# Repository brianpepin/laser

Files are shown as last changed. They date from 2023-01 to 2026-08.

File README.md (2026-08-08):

# The Laser Project
This repository contains a design for a diode pumped solid state laser that emits a green 532nm beam.  The unit is battery operated and rechargable with a runtime of approximately 30 minutes.

## Versions
Version 2.1 of the hardware and software is now live. Here is a summary of the changes:
1. The control board now uses a more modern MCU. Display refreshes are 8x faster and I was able to remove a number of components from the board due to the enhanced peripheral support on the new MCU.
2. Encoders are now velocity sensitive.
3. Calibration for the output power monitor now can be done through the UI.
4. The laser design has changed and the maximum output power is now 3x what it was in version 1.

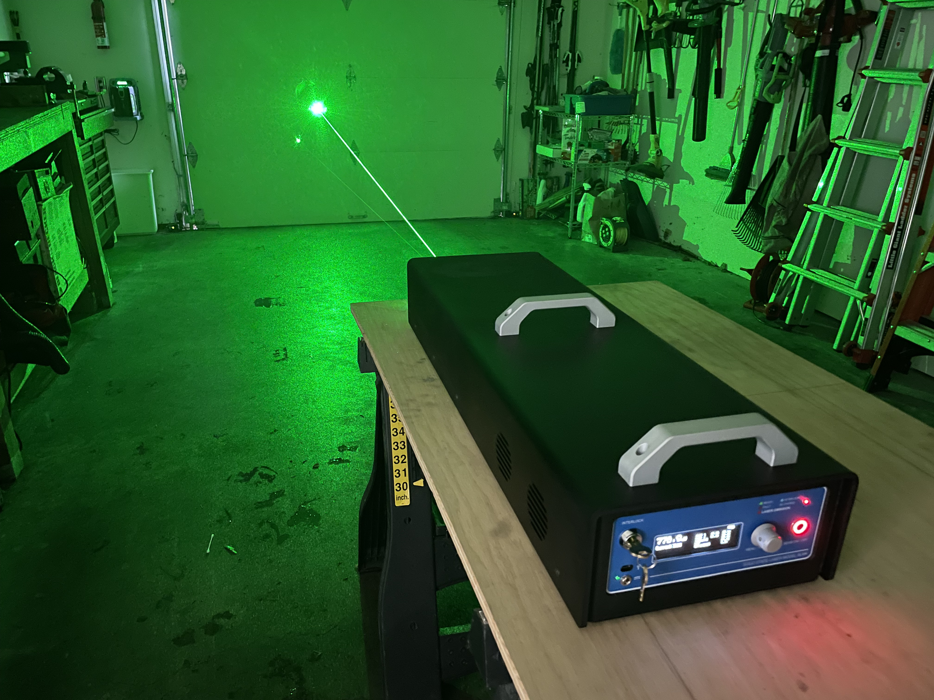
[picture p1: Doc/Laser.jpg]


## Repository Organization

The repository contains the following directories.

### Hardware
The Hardware directory contains KiCad files for schematics and board designs for the electronics.  There are three boards in total:

1. The **Power** board is the main power supply. It contains a battery charger, power control, power monitoring, fan controller, and two 50A constant current power supplies.
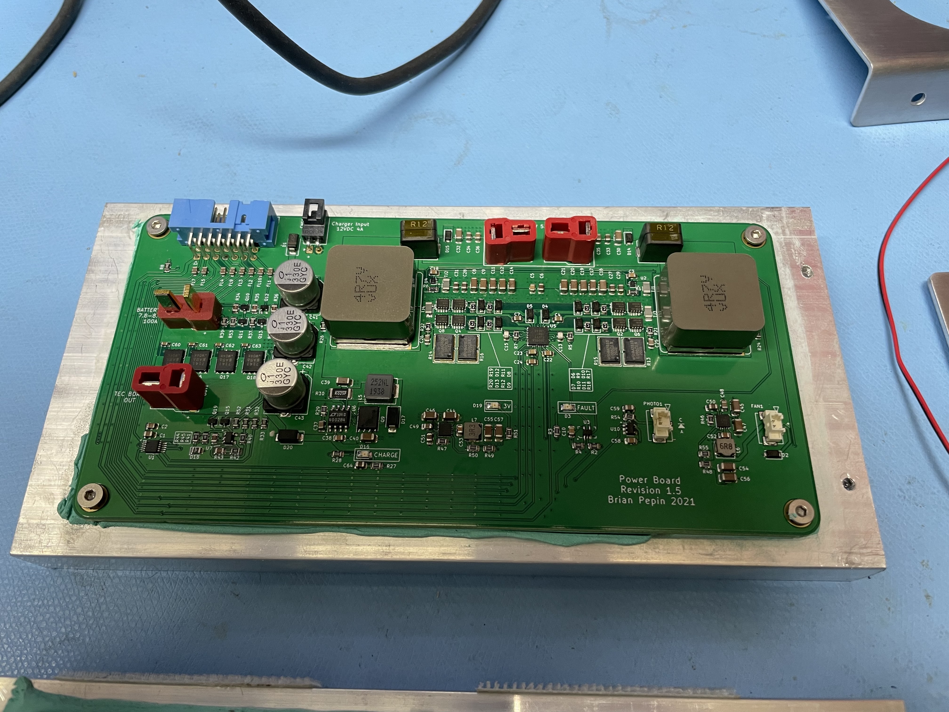
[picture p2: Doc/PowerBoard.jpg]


2. The **TEC** board contains four independent channels for controlling thermo-electric coolers. Each channel can control up to 20A of cooling using direct battery voltage.
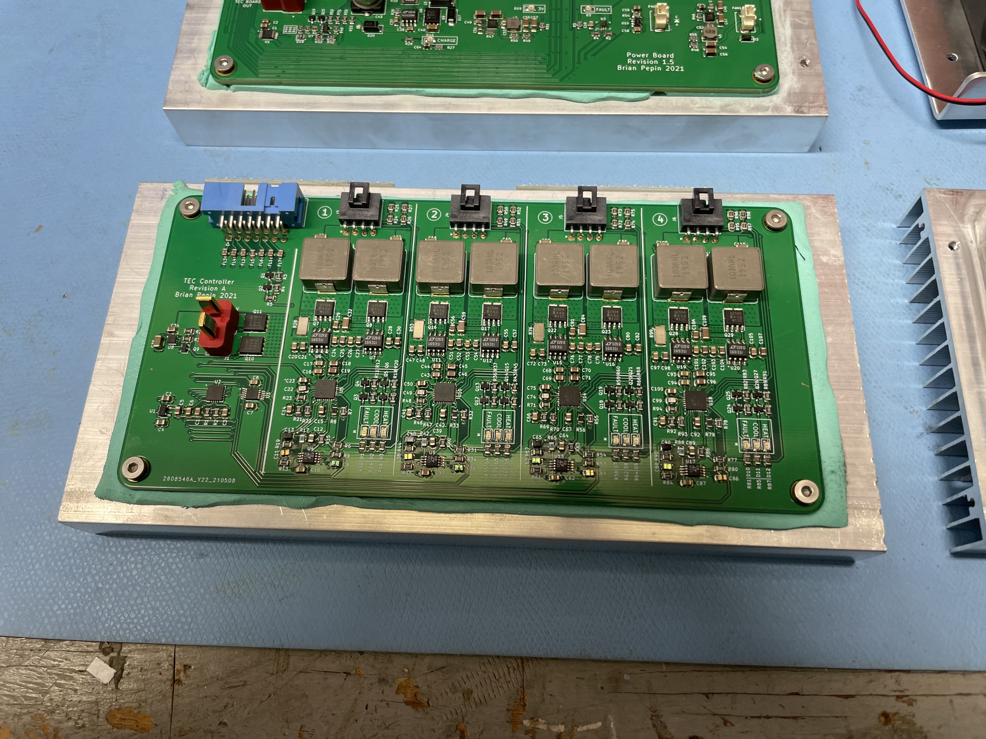
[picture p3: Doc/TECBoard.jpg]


3. The **Control** board is a small MCU and display for running the laser.  The board is based on the aging ATMEGA328p....but it would be easy to swap this to a newer MCU.

**Update:** Version 2.1 of the hardware now uses AVR128DB64 as it's MCU. This MCU has a lot more memory, a much faster speed, and perhipherial updates (like controllable schmitt triggers on inputs) that greatly simplified the rest of the board.

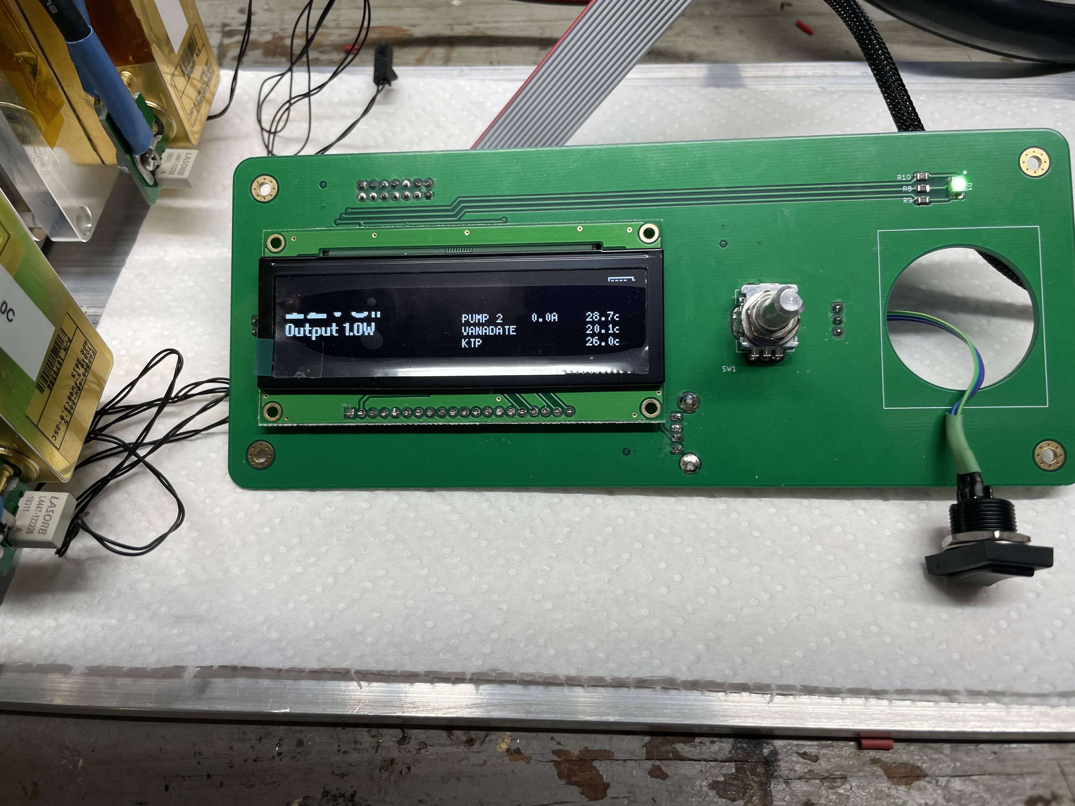
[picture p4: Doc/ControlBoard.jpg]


The power and TEC boards must both be bonded to heat sinks on the underside of the board using a non-conductive thermal layer. Boards use Deans connectors for high power and these connectors were modified (pins trimmed) so when soldered the back of the board remains relatively flat.

The system is designed to run off a 2S LiPo pack (I'm using two 8Ah packs in parallel). If you need higher voltage for the TECs you can go to 3S but may need to modify the charging circuit, which is designed for a 2S cell.

### Software
The software directory contains the source code for the controller. It uses Platform.IO in Visual Studio Code and levages Arduino libraries for convenience, especially for driving the display. Installing Platform.IO should be sufficient to find dependent libraries.
The software is organized to have a lib directory that contains generic driver code for chips used on each of the boards.  In the src directory these generic classes are wrapped by higher level classes that abstract their use.  For example, lib has directories called ADC104S021 and DAC108S085 for controlling ADC and DAC chips, and src has a class called TEC that uses both these lower level classes but provides an interface in degrees C.

### Optics
Optics contains files relevant to the optical layout.  Files ending in .rez are Rezonator files, which is an open-source program available at http://www.rezonator.orion-project.org which can do ABCD matrix analysis of laser cavities for stability and Gaussian beam analysis.

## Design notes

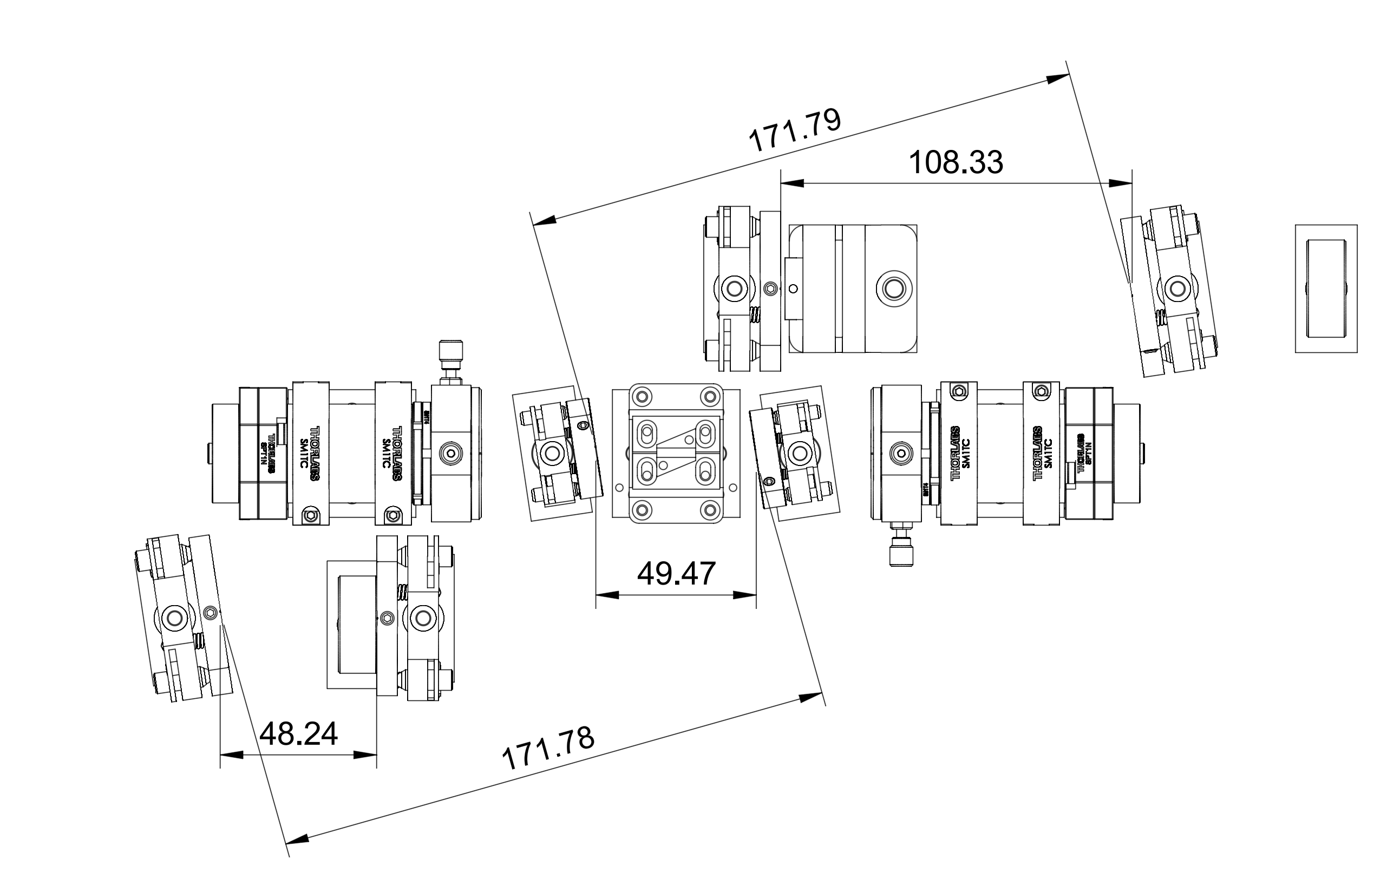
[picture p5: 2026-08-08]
Optics/ResonatorDiagram.png

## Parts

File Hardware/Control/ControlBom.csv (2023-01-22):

Id | Designator | Package | Quantity | Designation | Supplier and ref
1 | SW1 | EN11-HSM | 1 | EN11-HSM1AF20
2 | H4,H3,H2,H1 | MountingHole_3mm_Pad_Via | 4 | MountingHole_Pad
3 | USB1 | USB-A1HSW6 | 1 | USB-A1HSW6
4 | C10,C15,C11,C9,C5,C4,C3 | C_0805_2012Metric | 7 | .1uF
5 | U3 | SSOP-20_5.3x7.2mm_P0.65mm | 1 | MAX6818EAP+T
6 | D1 | LED_Avago_PLCC4_3.2x2.8mm_CW | 1 | AAA3528LSEKJ3ZGKQBKS
7 | U4 | TQFP-32_7x7mm_P0.8mm | 1 | ATMEGA328P-AU
8 | Y1 | Crystal_SMD_3225-4Pin_3.2x2.5mm | 1 | ABM8AIG-20.000MHZ-4-T
9 | U5 | SOT-23-6 | 1 | ESDALD05UD4
10 | U2 | SSOP-16_3.9x4.9mm_P0.635mm | 1 | FT230XS-U
11 | U1 | TSSOP-16_4.4x5mm_P0.65mm | 1 | XRA1402IG16TR-F
12 | SW3 | PinHeader_1x03_P2.54mm_Vertical | 1 | TRD11G10WL
13 | SW2 | PinHeader_1x02_P2.54mm_Vertical | 1 | KO128B2007
14 | R10 | R_0805_2012Metric | 1 | 600
15 | R9,R8 | R_0805_2012Metric | 2 | 175
16 | R7,R6 | R_0805_2012Metric | 2 | 27
17 | R3,R2,R1 | R_0805_2012Metric | 3 | 10k
18 | MCU1 | IDC-Header_2x07_P2.54mm_Vertical | 1 | 2-1761603-5
19 | ISP1 | TC2050-IDC | 1 | AVR_ISP_10_SERIAL
20 | DISP1 | NHD-3.12-25664UC | 1 | NHD-3.12-25664UCW2
21 | C14,C13,C12 | C_1206_3216Metric | 3 | 22uF
22 | C8,C7 | C_0805_2012Metric | 2 | 18pF
23 | C6 | C_0805_2012Metric | 1 | 4.7uF
24 | C2,C1 | C_0805_2012Metric | 2 | 47pF

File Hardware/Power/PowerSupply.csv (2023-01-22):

Reference | Quantity | Value | Footprint | Datasheet | PartNo | Description
C1 C35 C36 C59 | 4 | 1uF | Capacitor_SMD:C_0805_2012Metric | ~ | UMF212B7105KGHT
C13 C15 | 2 | 220pF | Capacitor_SMD:C_0805_2012Metric | ~ | C0805C221K1HACTU
C2 C3 C5 C10 C18 C22 C24 C38 C52 C53 C58 | 11 | .1uF | Capacitor_SMD:C_0805_2012Metric | ~ | C0805X104M5RACTU
C8 C9 C11 C12 C14 C16 C17 C19 C20 C21 C44 C45 C46 C47 | 14 | 47uF | Capacitor_SMD:C_1206_3216Metric | ~ | C3216JB1E476M160AC
C23 | 1 | 2.2uF | Capacitor_SMD:C_0805_2012Metric | ~ | GCM21BR71E225KA73L
C25 C26 | 2 | 2200pF | Capacitor_SMD:C_0805_2012Metric | ~ | C0805C222K3GECTU
C30 C32 C39 C54 C55 C56 C57 | 7 | 22uF | Capacitor_SMD:C_1206_3216Metric | ~ | C3216X5R1V226M160AC
C6 C27 C28 C29 C31 C33 C34 C50 C51 C64 | 10 | 4.7uF | Capacitor_SMD:C_0805_2012Metric | ~ | JMK212B7475KGHT
C37 | 1 | .47uF | Capacitor_SMD:C_0805_2012Metric | ~ | C2012X7R1E474K125AA
C40 | 1 | 10uF | Capacitor_SMD:C_1206_3216Metric | ~ | GMK316AB7106KL-TR
C41 C42 C43 | 3 | 330uF | Capacitor_SMD:CP_Elec_10x10 | ~ | GYC1E331MCQ1GS
C48 C49 | 2 | 7.5nF | Capacitor_SMD:C_0805_2012Metric | ~ | C0805C752F8HACTU
C60 C61 C62 C63 | 4 | .22uF | Capacitor_SMD:C_0603_1608Metric | ~
C4 C7 | 2 | .22uF | Capacitor_SMD:C_0805_2012Metric | ~ | GRM21AR72A224KAC5K
CHG1 | 1 | 105313-1102 | Connector_Molex:Molex_Nano-Fit_105313-xx02_1x02_P2.50mm_Horizontal | ~ | 105313-1102
D1 D17 D20 | 3 | CDBA540-HF | Diode_SMD:D_SMA | ~ | CDBA540-HF
D16 D19 | 2 | SM0805GCL | LED_SMD:LED_0805_2012Metric_Castellated | ~ | SM0805GCL
D18 | 1 | BZY55B3V0 RBG | Diode_SMD:D_0805_2012Metric | ~ | BZY55B3V0 RBG
D2 D4 D5 D6 D7 D8 D9 D10 D11 D12 D13 D14 D15 | 13 | V1FM15-M3/H | Diode_SMD:D_SOD-123F | ~ | V1FM15-M3/H
D3 | 1 | SM0805HCL | LED_SMD:LED_0805_2012Metric_Castellated | ~ | SM0805HCL
FAN1 PHOTO1 | 2 | 53398-0267 | ultra-librarian:533980267 | ~ | 53398-0267
FL1 FL2 FL3 FL4 FL5 FL7 FL9 FL10 | 8 | NFL21SP206X1C7D | pepin-footprints:EMI_805 | http://www.murata.com/~/media/webrenewal/support/library/catalog/products/emc/emifil/c31e.ashx?la=en-gb | NFL21SP206X1C7D
H1 H2 H3 H4 | 4 | MountingHole | MountingHole:MountingHole_3.2mm_M3_Pad_Via | ~
IN1 | 1 | DEANS | pepin-footprints:Connector_Deans_Male | http://cdn.sparkfun.com/datasheets/Prototyping/deans_connector_PRT-11864.pdf
L1 L2 | 2 | 4.7uH | PowerSupplyFootprints:Inductor_Kemet_MPX1D2213 | ~ | MPXV1D2213L4R7
L3 L4 | 2 | 120nH | PowerSupplyFootprints:Inductor_TDK_VLBS1007083 | ~ | VLBU1007090T-R12L
L5 | 1 | 2.5uH | PowerSupplyFootprints:Inductor_Pulse_PA4341 | ~ | PA4341.252NLT
L6 | 1 | 6.8uH | PowerSupplyFootprints:Inductor_SRP0412 | ~ | SRP0412-6R8K
L7 | 1 | 3.3uH | PowerSupplyFootprints:Inductor_SRP0412 | ~ | SRP0412-3R3K
MCU1 | 1 | 2-1761605-5 | Connector_IDC:IDC-Header_2x07_P2.54mm_Horizontal | ~ | 2-1761605-5
OUT1 LASER1 LASER2 | 3 | DEANS | pepin-footprints:Connector_Deans_Female | http://cdn.sparkfun.com/datasheets/Prototyping/deans_connector_PRT-11864.pdf
Q11 Q12 Q13 | 3 | 2N7002PW | Package_TO_SOT_SMD:SOT-323_SC-70 | https://www.onsemi.com/pub/Collateral/NDS7002A-D.PDF | 2N7002PW,115
Q10 Q15 Q19 | 3 | BSS84 | Package_TO_SOT_SMD:SOT-323_SC-70 | http://assets.nexperia.com/documents/data-sheet/BSS84.pdf | BSS84PWH6327XT
Q1 Q2 Q3 Q4 Q5 Q6 Q7 Q8 | 8 | PSMN1R5-25MLHX | Package_TO_SOT_SMD:LFPAK33 | https://assets.nexperia.com/documents/data-sheet/PSMN1R8-30MLH.pdf | PSMN1R5-25MLHX
Q9 Q14 Q16 Q17 Q18 | 5 | Si7141DP | Package_SO:PowerPAK_SO-8_Single | https://www.vishay.com/docs/65596/si7141dp.pdf | SI7141DP-T1-GE3
R13 R14 R15 R16 | 4 | .008 | PowerSupplyFootprints:R_2818_7158Metric_Kelvin | ~ | WSHM28188L000FEA
R9 R10 R11 R12 R17 R18 R19 R20 | 8 | 4.7 | Resistor_SMD:R_0805_2012Metric | ~ | ERJ-P06J4R7V
R21 R22 | 2 | 1.2 | Resistor_SMD:R_0805_2012Metric | ~ | ERJ-6BQF1R2V
R23 R25 | 2 | 4.64k | Resistor_SMD:R_0805_2012Metric | ~ | ERJ-6ENF4641V
R29 | 1 | 2.2k | Resistor_SMD:R_0805_2012Metric | ~ | ERJ-PB6B2201V
R3 R27 R51 | 3 | 560 | Resistor_SMD:R_0805_2012Metric | ~ | ERJ-6ENF5600V
R30 | 1 | .025 | Resistor_SMD:R_2010_5025Metric | ~ | WSL2010R0250FEA
R34 R35 R36 R38 R41 R43 | 6 | 100k | Resistor_SMD:R_0805_2012Metric | ~ | SFR10EZPJ104
R40 R42 R44 R45 | 4 | 1k | Resistor_SMD:R_0805_2012Metric | ~ | ERJ-P06J102V
R46 R47 | 2 | 19.1k | Resistor_SMD:R_0805_2012Metric | ~ | ERJ-6ENF1912V
R48 | 1 | 54.9k | Resistor_SMD:R_0805_2012Metric | ~ | ERJ-6ENF5492V
R49 | 1 | 53.6k | Resistor_SMD:R_0805_2012Metric | ~ | ERJ-6ENF5362V
R50 | 1 | 20.5k | Resistor_SMD:R_0805_2012Metric | ~ | ERJ-6ENF2052V
R53 | 1 | 5.1k | Resistor_SMD:R_0805_2012Metric | ~
R54 | 1 | 20k | Resistor_SMD:R_0805_2012Metric | ~ | ERJ-P06D60R4V
R55 | 1 | 12k | Resistor_SMD:R_0805_2012Metric | ~ | ERJ-P06F1202V
R1 R6 | 2 | 332k | Resistor_SMD:R_0805_2012Metric | ~ | RT0805FRE07332KL
R5 R7 | 2 | 5.36k | Resistor_SMD:R_0805_2012Metric | ~ | ERJ-6ENF5361V
R2 R4 R8 R24 R26 R28 R31 R32 R33 R37 R39 R52 | 12 | 10k | Resistor_SMD:R_0805_2012Metric | ~ | ERJ-6ENF1002V
TJ1 TJ2 TJ3 TJ4 | 4 | oo | Resistor_SMD:R_1206_3216Metric | https://www.mouser.com/datasheet/2/427/thjp-1709843.pdf | THJP1206AST1 | 1225 sideways mount
TP1 | 1 | Out1+ | TestPoint:TestPoint_THTPad_1.0x1.0mm_Drill0.5mm | ~
TP2 | 1 | Out1- | TestPoint:TestPoint_THTPad_1.0x1.0mm_Drill0.5mm | ~
TP3 | 1 | Out2+ | TestPoint:TestPoint_THTPad_1.0x1.0mm_Drill0.5mm | ~
TP4 | 1 | Out2- | TestPoint:TestPoint_THTPad_1.0x1.0mm_Drill0.5mm | ~
U1 | 1 | ADC104S021 | Package_SO:VSSOP-10_3x3mm_P0.5mm |  | ADC104S021CIMMX/NOPB
U3 | 1 | SN74LVC1G08DCK3 | digikey-footprints:SC-70-5 | http://www.ti.com/lit/sg/scyt129e/scyt129e.pdf | SN74LVC1G08DCK3
U2 U4 | 2 | TMP390-Q1 | PowerSupplyFootprints:SOT-563 |  | TMP390AQDRLRQ1
U5 | 1 | MAX20096ATJ_VY+ | Package_DFN_QFN:QFN-32-1EP_5x5mm_P0.5mm_EP3.1x3.1mm_ThermalVias |  | MAX20096ATJ/VY+
U6 | 1 | LTC4002ES8-8.4 | Package_SO:SOIC-8_3.9x4.9mm_P1.27mm | https://www.analog.com/media/en/technical-documentation/data-sheets/4002f.pdf | LTC4002ES8-8.4#PBF
U7 U10 | 2 | LTC2066IS5#TRPBF | Package_TO_SOT_SMD:SOT-23-5 | http://www.ti.com/lit/ds/symlink/tlv2375.pdf | LTC2066IS5#TRPBF
U8 U9 | 2 | MAX17643 | PowerSupplyFootprints:DFN-12-1EP_3x3mm_P0.5mm_EP2.05x2.5mm |  | MAX17643ATC+

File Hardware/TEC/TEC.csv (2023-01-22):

Id | Designator | Package | Quantity | Designation | Supplier and ref
1 | L1,L8,L7,L6,L5,L4,L3,L2 | L_Pulse_PA4343_2 | 8 | 10uH
2 | U2 | WQFN-16-1EP_4x4mm_P0.5mm_EP2.6x2.6mm_ThermalVias | 1 | DAC108S085CISQ
3 | J2 | IDC-Header_2x07_P2.54mm_Horizontal | 1 | Data
4 | U8 | WSON-6-1EP_2x2mm_P0.65mm_EP1x1.6mm_ThermalVias | 1 | TPS7A26
5 | C35,C110,C108,C85,C83,C60,C58,C33,C31 | C_1206_3216Metric | 9 | 22uF
6 | C34,C106,C96,C95,C81,C71,C70,C56,C46,C45,C29,C19,C18 | C_0805_2012Metric | 13 | 10uF
7 | NT4,NT3,NT2,NT1 | NetTie-2_SMD_Pad0.5mm | 4 | Net-Tie_2
8 | U20,U19,U16,U15,U12,U11,U7,U6 | SO-8_3.9x4.9mm_P1.27mm | 8 | LTC1693-1
9 | U18,U14,U10,U5 | QFN-32-1EP_5x5mm_P0.5mm_EP3.45x3.45mm_ThermalVias | 4 | LTC1923EUH
10 | U17,U13,U9,U4 | MSOP-8_3x3mm_P0.65mm | 4 | LTC2053
11 | R99,R76,R53,R28 | R_2010_5025Metric | 4 | .010
12 | R98,R96,R75,R73,R52,R50,R27,R25 | R_0805_2012Metric | 8 | 2050
13 | R97,R95,R74,R72,R51,R49,R26,R24 | R_0805_2012Metric | 8 | 8060
14 | R94,R92,R71,R69,R48,R46,R2,R1,R23,R21 | R_0805_2012Metric | 10 | 10k
15 | R93,R70,R47,R22 | R_0805_2012Metric | 4 | 82k
16 | R91,R89,R83,R82,R68,R66,R60,R59,R45,R43,R37,R36,R5,R4,R3,R30,R29,R20,R18,R12,R11 | R_0805_2012Metric | 21 | 100k
17 | R90,R67,R44,R19 | R_0805_2012Metric | 4 | 10M 1%
18 | R88,R65,R42,R17 | R_0805_2012Metric | 4 | 1M 1%
19 | R87,R85,R81,R64,R62,R58,R41,R39,R35,R16,R14,R10 | R_0805_2012Metric | 12 | 1.5k
20 | R86,R63,R40,R15 | R_0805_2012Metric | 4 | 1k 1%
21 | R84,R61,R38,R13 | R_0805_2012Metric | 4 | 9.09k 1%
22 | R80,R57,R34,R9 | R_0805_2012Metric | 4 | 10k 1%
23 | R79,R56,R33,R8 | R_0805_2012Metric | 4 | 13.3k 1%
24 | R78,R55,R32,R7 | R_0805_2012Metric | 4 | 6.65k 1%
25 | R77,R54,R31,R6 | R_0805_2012Metric | 4 | 15.4k 1%
26 | Q29,Q28,Q23,Q22,Q17,Q16,Q8,Q7 | PowerPAK_SO-8_Dual | 8 | SQJ504EP
27 | Q27,Q26,Q25,Q24,Q21,Q20,Q19,Q18,Q15,Q14,Q13,Q12,Q2,Q1,Q9,Q6,Q5,Q4,Q3 | SOT-323_SC-70 | 19 | 2N7002PW
28 | J6,J5,J4,J3 | Molex_Nano-Fit_105313-xx04_1x04_P2.50mm_Horizontal | 4 | Conn_01x04
29 | D12,D9,D6,D3 | LED_0805_2012Metric | 4 | YEL
30 | D11,D8,D5,D2 | LED_0805_2012Metric | 4 | BLU
31 | D10,D7,D4,D1 | LED_0805_2012Metric | 4 | RED
32 | C109,C84,C59,C32 | C_1206_3216Metric | 4 | 47uF
33 | C107,C104,C102,C98,C82,C79,C77,C73,C57,C54,C52,C48,C30,C27,C25,C21 | C_0805_2012Metric | 16 | 4.7uF
34 | C105,C103,C101,C97,C94,C93,C91,C87,C80,C78,C76,C72,C69,C68,C66,C62,C55,C53,C51,C47,C44,C43,C41,C37,C3,C1,C28,C26,C24,C20,C17,C16,C14,C10,C8,C6 | C_0805_2012Metric | 36 | .1uF
35 | C100,C92,C89,C75,C67,C64,C50,C42,C39,C7,C23,C15,C12,C5,C4,C2 | C_0805_2012Metric | 16 | 1uF
36 | C99,C74,C49,C22 | C_0805_2012Metric | 4 | 150pF
37 | C90,C65,C40,C13 | C_0805_2012Metric | 4 | 4.7uF tant
38 | C88,C86,C63,C61,C38,C36,C11,C9 | C_0805_2012Metric | 8 | .1uF film
39 | H4,H3,H2,H1 | MountingHole_3mm_Pad_Via | 4 | MountingHole_Pad
40 | FL7,FL6,FL5,FL4,FL3,FL2,FL1 | EMI_805 | 7 | NFL21SP206X1C7D
41 | U3 | VSSOP-10_3x3mm_P0.5mm | 1 | ADC104S021
42 | U1 | SOT-23-5 | 1 | LP3985-3.0
43 | Q11,Q10 | PowerPAK_SO-8_Single | 2 | Si7141DP
44 | J1 | Connector_Deans_Male | 1 | DEANS

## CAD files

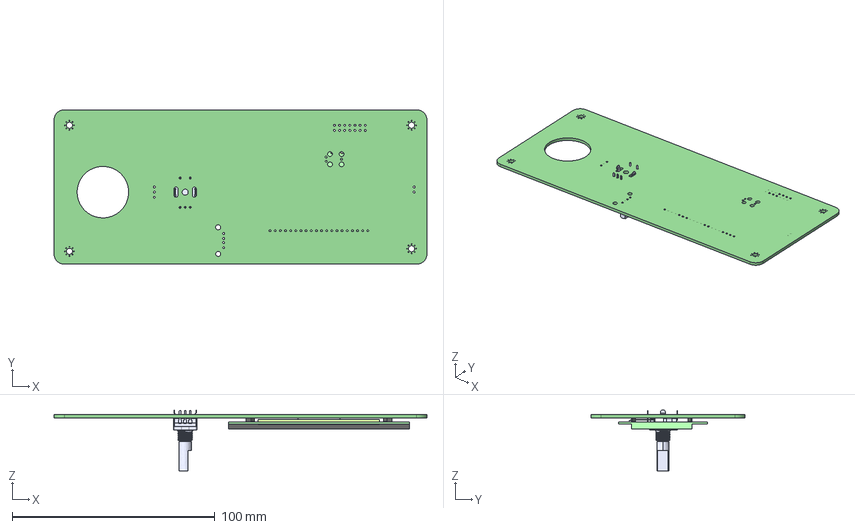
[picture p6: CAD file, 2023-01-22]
Hardware/Control/Control.step
184.2 x 76.2 x 30.1 mm
_autosave-Control PCB

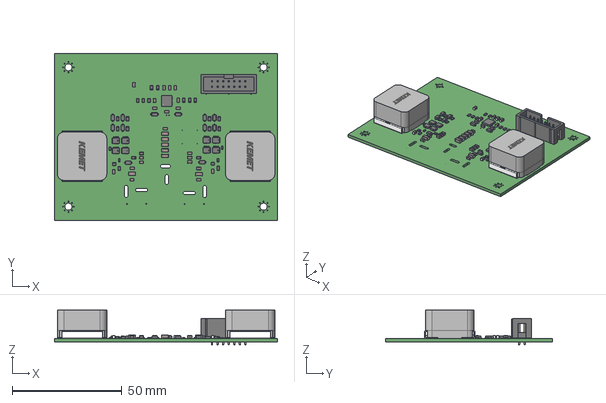
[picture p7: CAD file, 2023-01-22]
Hardware/Power/PowerSupply.step
101.6 x 76.2 x 15.9 mm

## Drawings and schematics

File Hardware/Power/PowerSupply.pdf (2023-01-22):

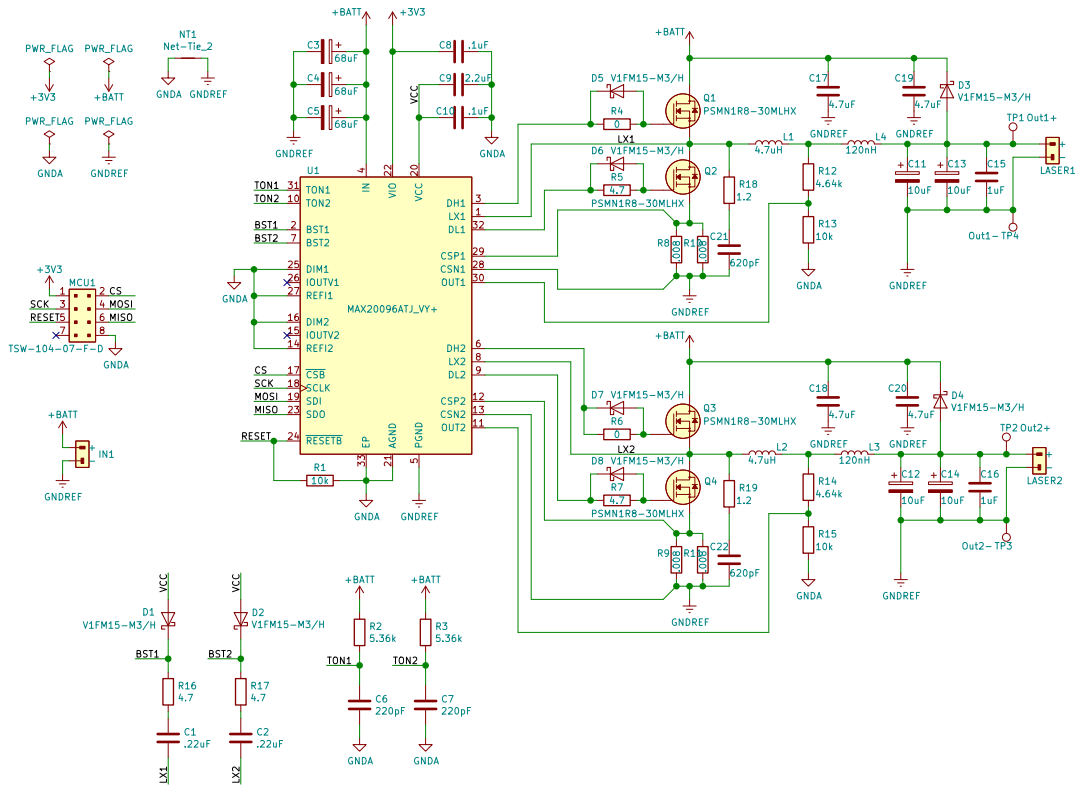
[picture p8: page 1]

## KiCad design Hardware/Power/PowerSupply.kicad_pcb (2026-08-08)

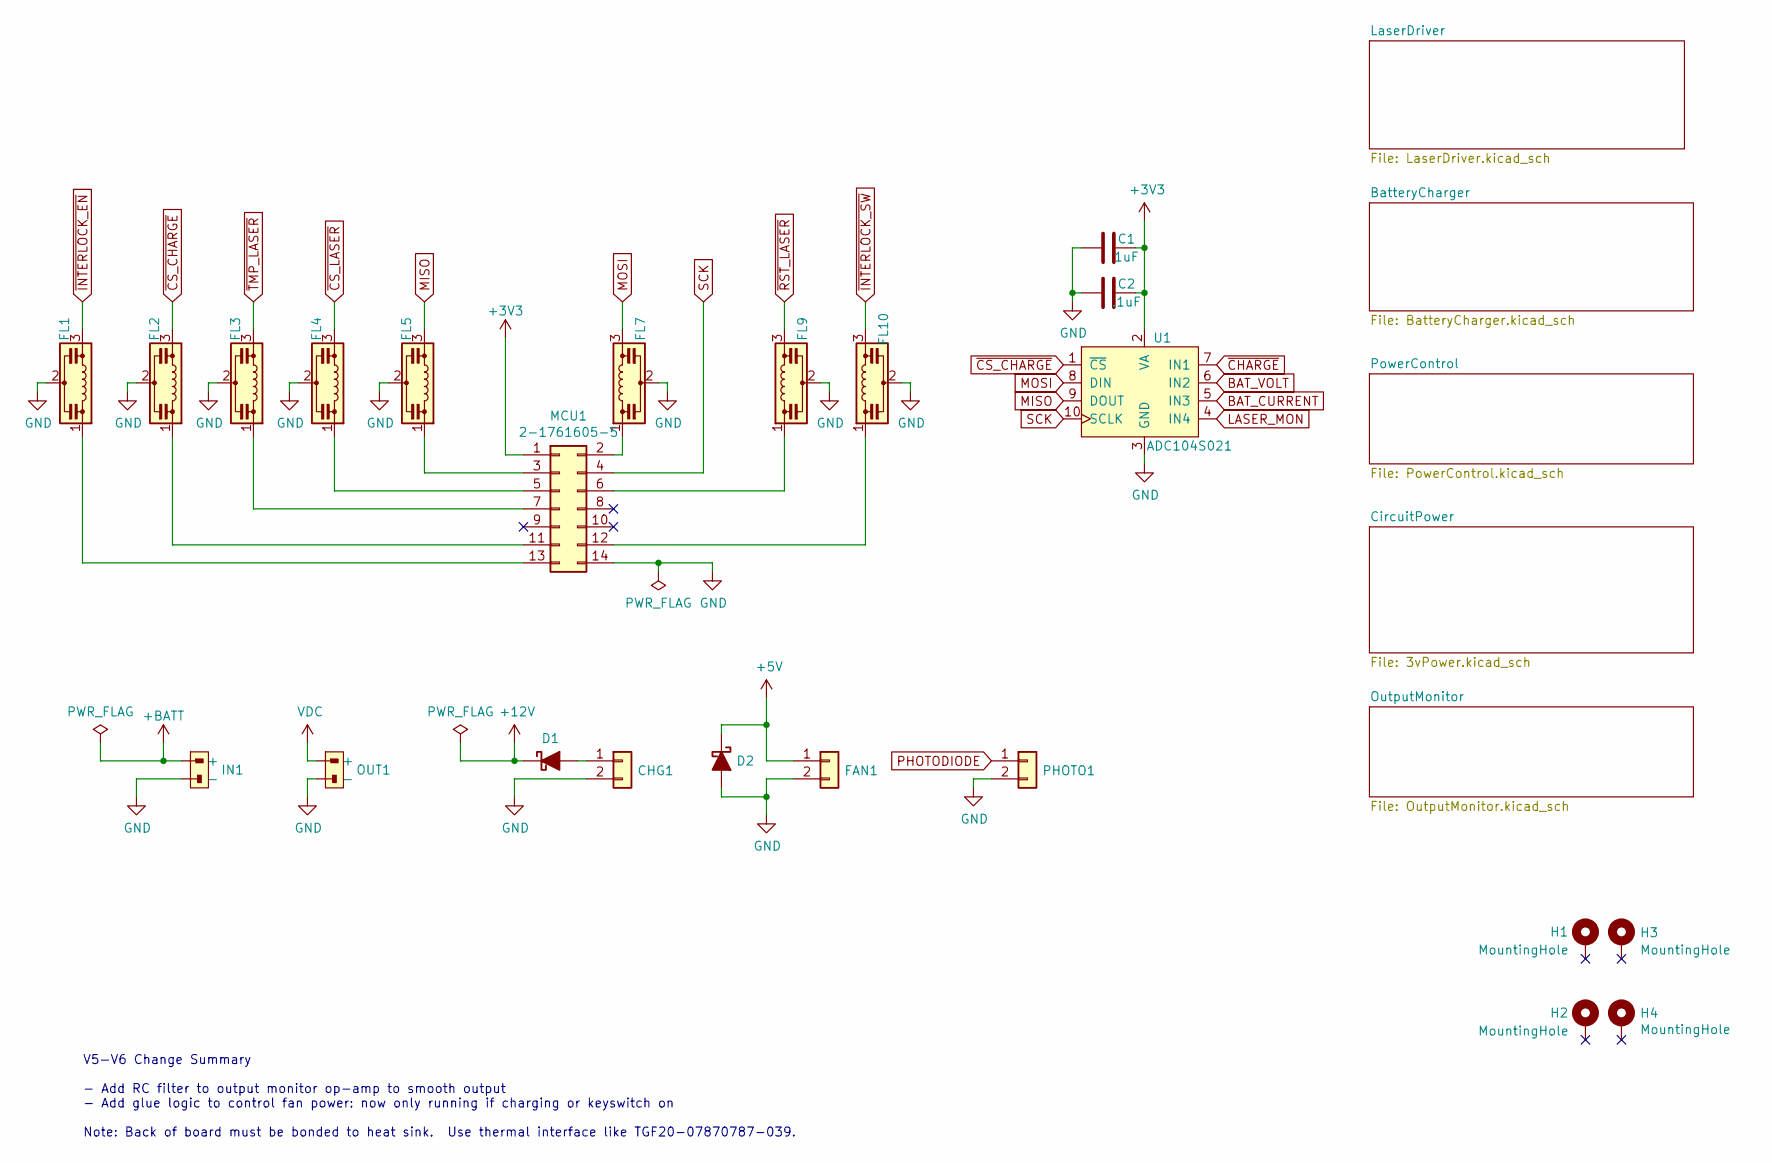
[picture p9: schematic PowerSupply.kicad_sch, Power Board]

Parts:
C1: 1uF; C_0805_2012Metric; PartNo UMF212B7105KGHT
C2: .1uF; C_0805_2012Metric; PartNo C0805X104M5RACTU
CHG1: 105313-1102; Molex_Nano-Fit_105313-xx02_1x02_P2.50mm_Horizontal; PartNo 105313-1102
D1: CDBA540-HF; D_SMA; PartNo CDBA540-HF
D2: V1FM15-M3/H; D_SOD-123F; PartNo V1FM15-M3/H
FAN1: 53398-0267; 533980267; PartNo 53398-0267
FL1, FL2, FL3, FL4, FL5, FL7, FL9, FL10: NFL21SP206X1C7D; EMI_805; PartNo NFL21SP206X1C7D
H1, H2, H3, H4: MountingHole; MountingHole_3.2mm_M3_Pad_Via
IN1: DEANS; Connector_Deans_Male
MCU1: 2-1761605-5; IDC-Header_2x07_P2.54mm_Horizontal; PartNo 2-1761605-5
OUT1: DEANS; Connector_Deans_Female
PHOTO1: 53398-0267; 533980267; PartNo 53398-0267
U1: ADC104S021; VSSOP-10_3x3mm_P0.5mm; PartNo ADC104S021CIMMX/NOPB

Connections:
+3V3: C1.1, C2.1, MCU1.1, U1.2 (VA); also elsewhere on the board
+5V: D2.1 (K), FAN1.1; also elsewhere on the board
+12V: D1.1 (K); also elsewhere on the board
+BATT: IN1.+; also elsewhere on the board
BAT_CURRENT: U1.5 (IN3); also elsewhere on the board
BAT_VOLT: U1.6 (IN2); also elsewhere on the board
GND: C1.2, C2.2, CHG1.2, D2.2 (A), FAN1.2, FL1.2, FL2.2, FL3.2, FL4.2, FL5.2, FL7.2, FL9.2, FL10.2, IN1.-, MCU1.14, OUT1.-, PHOTO1.2, U1.3 (GND); also elsewhere on the board
LASER_MON: U1.4 (IN4); also elsewhere on the board
MISO: FL5.3, U1.9 (DOUT); also elsewhere on the board
MOSI: FL7.3, U1.8 (DIN); also elsewhere on the board
unnamed: CHG1.1, D1.2 (A)
unnamed: FL7.1, MCU1.2
unnamed: FL5.1, MCU1.3
unnamed: FL4.1, MCU1.5
unnamed: FL9.1, MCU1.6
unnamed: FL3.1, MCU1.7
unnamed: FL2.1, MCU1.11
unnamed: FL10.1, MCU1.12
unnamed: FL1.1, MCU1.13
PHOTODIODE: PHOTO1.1; also elsewhere on the board
SCK: MCU1.4, U1.10 (SCLK); also elsewhere on the board
VDC: OUT1.+; also elsewhere on the board
~CHARGE: U1.7 (IN1); also elsewhere on the board
~CS_CHARGE: FL2.3, U1.1 (~CS)
~CS_LASER: FL4.3; also elsewhere on the board
~INTERLOCK_EN: FL1.3; also elsewhere on the board
~INTERLOCK_SW: FL10.3; also elsewhere on the board
~RST_LASER: FL9.3; also elsewhere on the board
~TMP_LASER: FL3.3; also elsewhere on the board

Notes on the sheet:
V5-V6 Change Summary - Add RC filter to output monitor op-amp to smooth output - Add glue logic to control fan power: now only running if charging or keyswitch on Note: Back of board must be bonded to heat sink. Use thermal interface like TGF20-07870787-039.

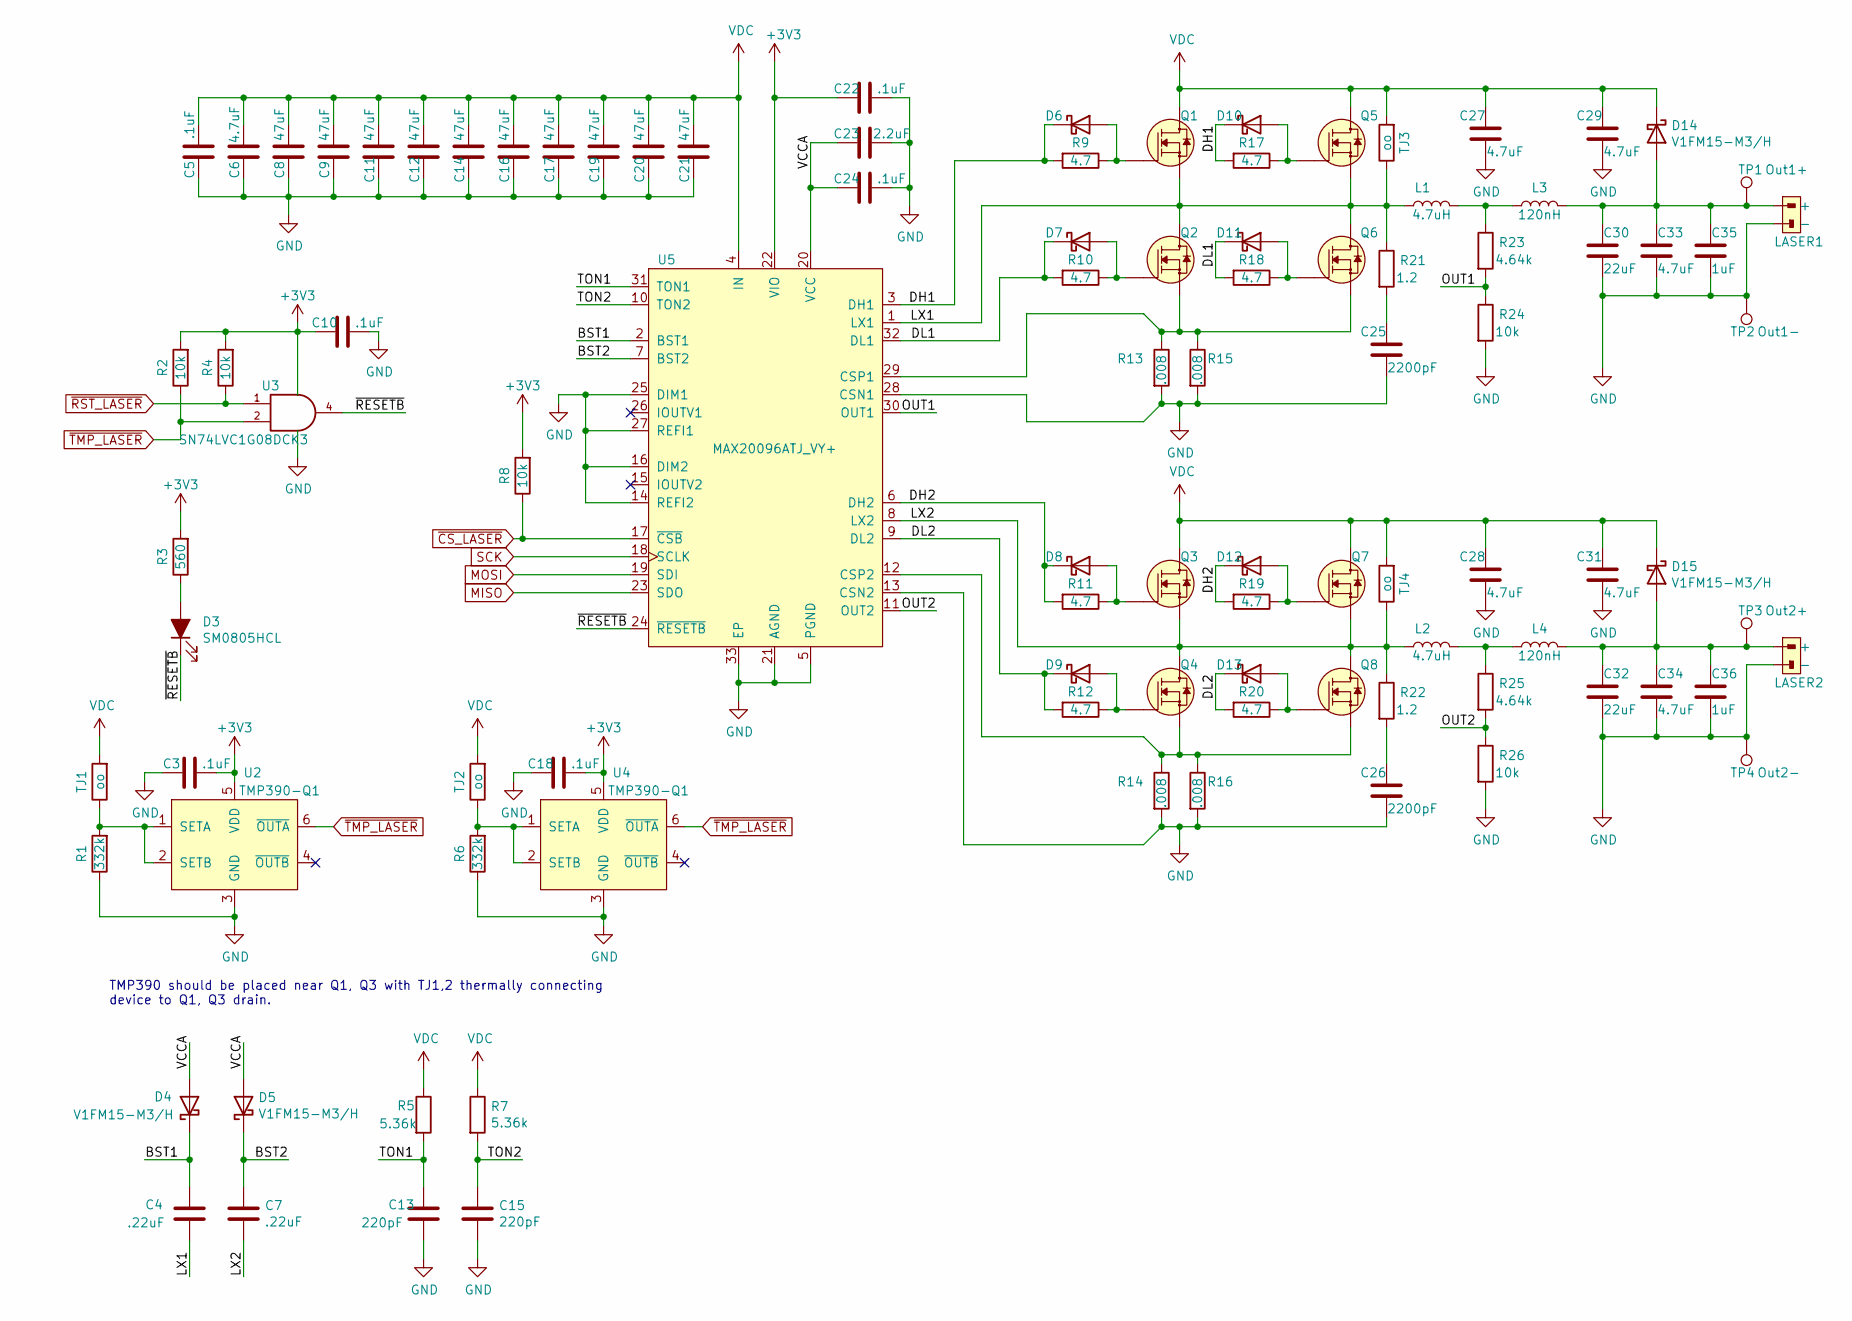
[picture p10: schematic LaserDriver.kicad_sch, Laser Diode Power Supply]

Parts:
C3, C5, C10, C18, C22, C24: .1uF; C_0805_2012Metric; PartNo C0805X104M5RACTU
C4, C7: .22uF; C_0805_2012Metric; PartNo GRM21AR72A224KAC5K
C6, C27, C28, C29, C31, C33, C34: 4.7uF; C_0805_2012Metric; PartNo JMK212B7475KGHT
C8, C9, C11, C12, C14, C16, C17, C19, C20, C21: 47uF; C_1206_3216Metric; PartNo C3216JB1E476M160AC
C13, C15: 220pF; C_0805_2012Metric; PartNo C0805C221K1HACTU
C23: 2.2uF; C_0805_2012Metric; PartNo GCM21BR71E225KA73L
C25, C26: 2200pF; C_0805_2012Metric; PartNo C0805C222K3GECTU
C30, C32: 22uF; C_1206_3216Metric; PartNo C3216X5R1V226M160AC
C35, C36: 1uF; C_0805_2012Metric; PartNo UMF212B7105KGHT
D3: SM0805HCL; LED_0805_2012Metric; PartNo SM0805HCL
D4, D5, D6, D7, D8, D9, D10, D11, D12, D13, D14, D15: V1FM15-M3/H; D_SOD-123F; PartNo V1FM15-M3/H
L1, L2: 4.7uH; Inductor_Kemet_MPX1D2213; PartNo MPXV1D2213L4R7
L3, L4: 120nH; Inductor_TDK_VLBS1007083; PartNo VLBU1007090T-R12L
LASER1, LASER2: DEANS; Connector_Deans_Female
Q1, Q2, Q3, Q4, Q5, Q6, Q7, Q8: PSMN1R5-25MLHX; LFPAK33; PartNo PSMN1R5-25MLHX
R1, R6: 332k; R_0805_2012Metric; PartNo RT0805FRE07332KL
R2, R4, R8, R24, R26: 10k; R_0805_2012Metric; PartNo ERJ-6ENF1002V
R3: 560; R_0805_2012Metric; PartNo ERJ-6ENF5600V
R5, R7: 5.36k; R_0805_2012Metric; PartNo ERJ-6ENF5361V
R9, R10, R11, R12, R17, R18, R19, R20: 4.7; R_0805_2012Metric; PartNo ERJ-P06J4R7V
R13, R14, R15, R16: .008; R_2818_7158Metric_Kelvin; PartNo WSHM28188L000FEA
R21, R22: 1.2; R_0805_2012Metric; PartNo ERJ-6BQF1R2V
R23, R25: 4.64k; R_0805_2012Metric; PartNo ERJ-6ENF4641V
TJ1, TJ2, TJ3, TJ4: oo; R_1206_3216Metric; PartNo THJP1206AST1
TP1: Out1+; TestPoint_THTPad_1.0x1.0mm_Drill0.5mm
TP2: Out1-; TestPoint_THTPad_1.0x1.0mm_Drill0.5mm
TP3: Out2+; TestPoint_THTPad_1.0x1.0mm_Drill0.5mm
TP4: Out2-; TestPoint_THTPad_1.0x1.0mm_Drill0.5mm
U2, U4: TMP390-Q1; SOT-563; PartNo TMP390AQDRLRQ1
U3: SN74LVC1G08DCK3; SC-70-5; PartNo SN74LVC1G08DCK3
U5: MAX20096ATJ_VY+; QFN-32-1EP_5x5mm_P0.5mm_EP3.1x3.1mm_ThermalVias; PartNo MAX20096ATJ/VY+

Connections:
+3V3: C3.1, C10.2, C18.1, C22.2, R2.2, R3.2, R4.2, R8.2, U2.5 (VDD), U3.5 (VCC), U4.5 (VDD), U5.22 (VIO); also elsewhere on the board
/LaserDriver/BST1: C4.1, D4.1 (K), U5.2 (BST1)
/LaserDriver/BST2: C7.1, D5.1 (K), U5.7 (BST2)
/LaserDriver/DH1: D6.1 (K), D10.1 (K), R9.2, R17.2, U5.3 (DH1)
/LaserDriver/DH2: D8.1 (K), D12.1 (K), R11.2, R19.2, U5.6 (DH2)
/LaserDriver/DL1: D7.1 (K), D11.1 (K), R10.2, R18.2, U5.32 (DL1)
/LaserDriver/DL2: D9.1 (K), D13.1 (K), R12.2, R20.2, U5.9 (DL2)
/LaserDriver/LX1: C4.2, L1.1, Q1.1 (S), Q1.2 (S), Q1.3 (S), Q2.5 (D), Q5.1 (S), Q5.2 (S), Q5.3 (S), Q6.5 (D), R21.1, TJ3.1, U5.1 (LX1)
/LaserDriver/LX2: C7.2, L2.1, Q3.1 (S), Q3.2 (S), Q3.3 (S), Q4.5 (D), Q7.1 (S), Q7.2 (S), Q7.3 (S), Q8.5 (D), R22.1, TJ4.1, U5.8 (LX2)
/LaserDriver/OUT1: R23.2, R24.1, U5.30 (OUT1)
/LaserDriver/OUT2: R25.2, R26.1, U5.11 (OUT2)
/LaserDriver/TON1: C13.1, R5.2, U5.31 (TON1)
/LaserDriver/TON2: C15.1, R7.2, U5.10 (TON2)
/LaserDriver/VCCA: C23.2, C24.2, D4.2 (A), D5.2 (A), U5.20 (VCC)
/LaserDriver/~RESETB: D3.1 (K), U3.4, U5.24 (~RESETB)
GND: C3.2, C5.2, C6.2, C8.2, C9.2, C10.1, C11.2, C12.2, C13.2, C14.2, C15.2, C16.2, C17.2, C18.2, C19.2, C20.2, C21.2, C22.1, C23.1, C24.1, C25.2, C26.2, C27.2, C28.2, C29.2, C30.2, C31.2, C32.2, C33.2, C34.2, C35.2, C36.2, LASER1.-, LASER2.-, R1.1, R6.1, R13.2, R14.2, R15.2, R16.2, R24.2, R26.2, TP2.1, TP4.1, U2.3 (GND), U3.3 (GND), U4.3 (GND), U5.5 (PGND), U5.13 (CSN2), U5.14 (REFI2), U5.16 (DIM2), U5.21 (AGND), U5.25 (DIM1), U5.27 (REFI1), U5.28 (CSN1), U5.33 (EP); also elsewhere on the board
MISO: U5.23 (SDO); also elsewhere on the board
MOSI: U5.19 (SDI); also elsewhere on the board
unnamed: C25.1, R21.2
unnamed: C26.1, R22.2
unnamed: D3.2 (A), R3.1
unnamed: D6.2 (A), Q1.4 (G), R9.1
unnamed: D7.2 (A), Q2.4 (G), R10.1
unnamed: D8.2 (A), Q3.4 (G), R11.1
unnamed: D9.2 (A), Q4.4 (G), R12.1
unnamed: D10.2 (A), Q5.4 (G), R17.1
unnamed: D11.2 (A), Q6.4 (G), R18.1
unnamed: D12.2 (A), Q7.4 (G), R19.1
unnamed: D13.2 (A), Q8.4 (G), R20.1
unnamed: C30.1, C33.1, C35.1, D14.2 (A), L3.2, LASER1.+, TP1.1
unnamed: C32.1, C34.1, C36.1, D15.2 (A), L4.2, LASER2.+, TP3.1
unnamed: L1.2, L3.1, R23.1
unnamed: L2.2, L4.1, R25.1
unnamed: R1.2, TJ1.1, U2.1 (SETA), U2.2 (SETB)
unnamed: R6.2, TJ2.1, U4.1 (SETA), U4.2 (SETB)
unnamed: Q2.1 (S), Q2.2 (S), Q2.3 (S), Q6.1 (S), Q6.2 (S), Q6.3 (S), R13.1, R15.1, U5.29 (CSP1)
unnamed: Q4.1 (S), Q4.2 (S), Q4.3 (S), Q8.1 (S), Q8.2 (S), Q8.3 (S), R14.1, R16.1, U5.12 (CSP2)
SCK: U5.18 (SCLK); also elsewhere on the board
VDC: C5.1, C6.1, C8.1, C9.1, C11.1, C12.1, C14.1, C16.1, C17.1, C19.1, C20.1, C21.1, C27.1, C28.1, C29.1, C31.1, D14.1 (K), D15.1 (K), Q1.5 (D), Q3.5 (D), Q5.5 (D), Q7.5 (D), R5.1, R7.1, TJ1.2, TJ2.2, TJ3.2, TJ4.2, U5.4 (IN); also elsewhere on the board
~CS_LASER: R8.1, U5.17 (~CSB); also elsewhere on the board
~RST_LASER: R4.1, U3.1; also elsewhere on the board
~TMP_LASER: R2.1, U2.6 (~OUTA), U3.2, U4.6 (~OUTA); also elsewhere on the board

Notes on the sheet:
TMP390 should be placed near Q1, Q3 with TJ1,2 thermally connecting device to Q1, Q3 drain.

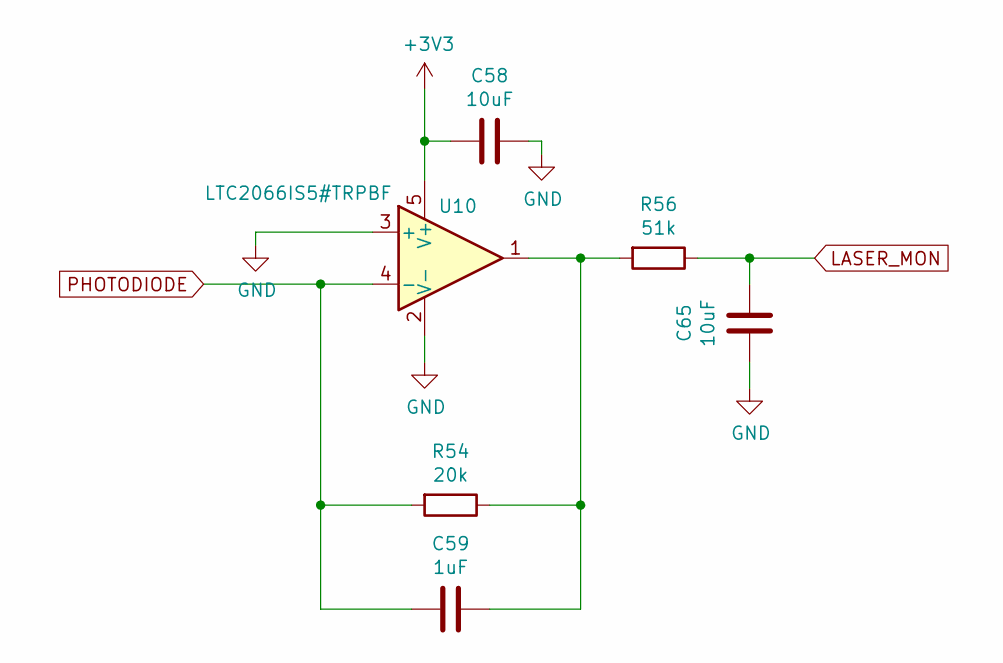
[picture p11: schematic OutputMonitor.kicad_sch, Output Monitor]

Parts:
C58, C65: 10uF; C_0805_2012Metric; PartNo C0805X104M5RACTU
C59: 1uF; C_0805_2012Metric; PartNo UMF212B7105KGHT
R54: 20k; R_0805_2012Metric; PartNo ERJ-P06D60R4V
R56: 51k; R_0805_2012Metric; PartNo ERJ-P06D60R4V
U10: LTC2066IS5#TRPBF; SOT-23-5; PartNo LTC2066IS5#TRPBF

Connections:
+3V3: C58.2, U10.5 (V+); also elsewhere on the board
GND: C58.1, C65.2, U10.2 (V-), U10.3 (+); also elsewhere on the board
LASER_MON: C65.1, R56.1; also elsewhere on the board
unnamed: C59.1, R54.1, R56.2, U10.1
PHOTODIODE: C59.2, R54.2, U10.4 (-); also elsewhere on the board

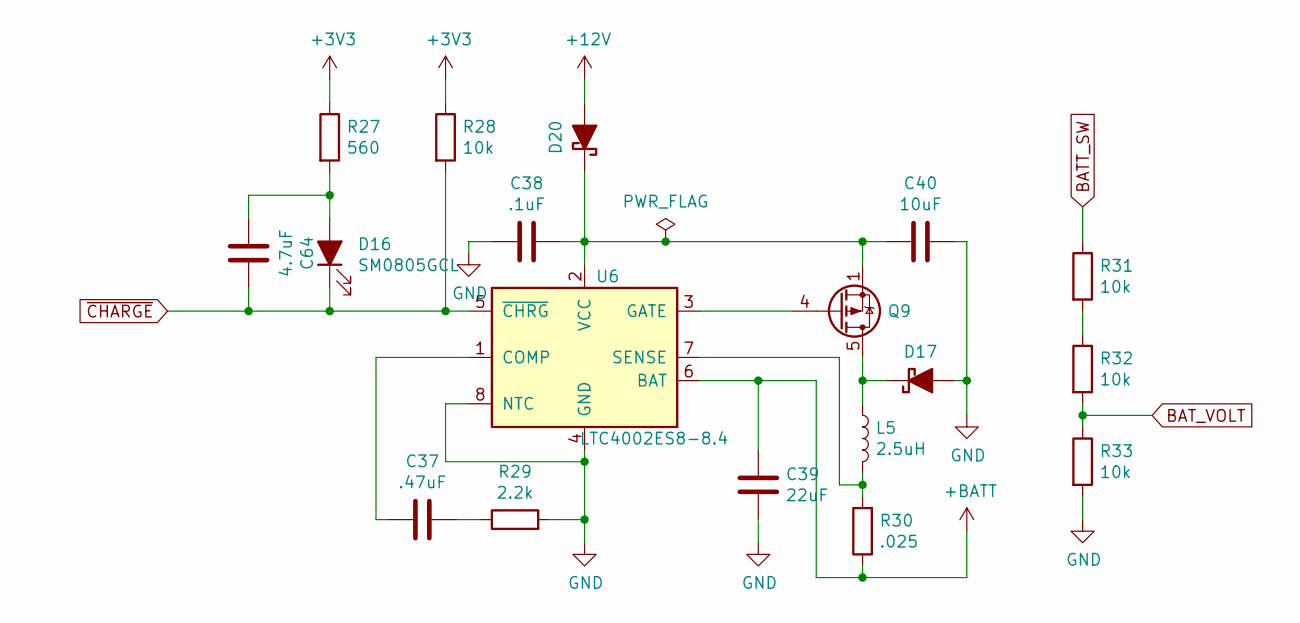
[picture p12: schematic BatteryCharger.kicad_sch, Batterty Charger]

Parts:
C37: .47uF; C_0805_2012Metric; PartNo C2012X7R1E474K125AA
C38: .1uF; C_0805_2012Metric; PartNo C0805X104M5RACTU
C39: 22uF; C_1206_3216Metric; PartNo C3216X5R1V226M160AC
C40: 10uF; C_1206_3216Metric; PartNo GMK316AB7106KL-TR
C64: 4.7uF; C_0805_2012Metric; PartNo JMK212B7475KGHT
D16: SM0805GCL; LED_0805_2012Metric; PartNo SM0805GCL
D17, D20: CDBA540-HF; D_SMA; PartNo CDBA540-HF
L5: 2.5uH; Inductor_Pulse_PA4341; PartNo PA4341.252NLT
Q9: Si7141DP; PowerPAK_SO-8_Single; PartNo SI7141DP-T1-GE3
R27: 560; R_0805_2012Metric; PartNo ERJ-6ENF5600V
R28, R31, R32, R33: 10k; R_0805_2012Metric; PartNo ERJ-6ENF1002V
R29: 2.2k; R_0805_2012Metric; PartNo ERJ-PB6B2201V
R30: .025; R_2010_5025Metric; PartNo WSL2010R0250FEA
U6: LTC4002ES8-8.4; SOIC-8_3.9x4.9mm_P1.27mm; PartNo LTC4002ES8-8.4#PBF

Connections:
+3V3: R27.1, R28.1; also elsewhere on the board
+12V: D20.2 (A); also elsewhere on the board
+BATT: C39.1, R30.1, U6.6 (BAT); also elsewhere on the board
BATT_SW: R31.1; also elsewhere on the board
BAT_VOLT: R32.2, R33.1; also elsewhere on the board
GND: C38.2, C39.2, C40.1, D17.2 (A), R29.2, R33.2, U6.4 (GND), U6.8 (NTC); also elsewhere on the board
unnamed: C37.1, R29.1
unnamed: C64.2, D16.2 (A), R27.2
unnamed: D17.1 (K), L5.1, Q9.5 (D)
unnamed: C38.1, C40.2, D20.1 (K), Q9.1 (S), Q9.2 (S), Q9.3 (S), U6.2 (VCC)
unnamed: Q9.4 (G), U6.3 (GATE)
unnamed: R31.2, R32.1
unnamed: C37.2, U6.1 (COMP)
unnamed: L5.2, R30.2, U6.7 (SENSE)
~CHARGE: C64.1, D16.1 (K), R28.2, U6.5 (~CHRG); also elsewhere on the board

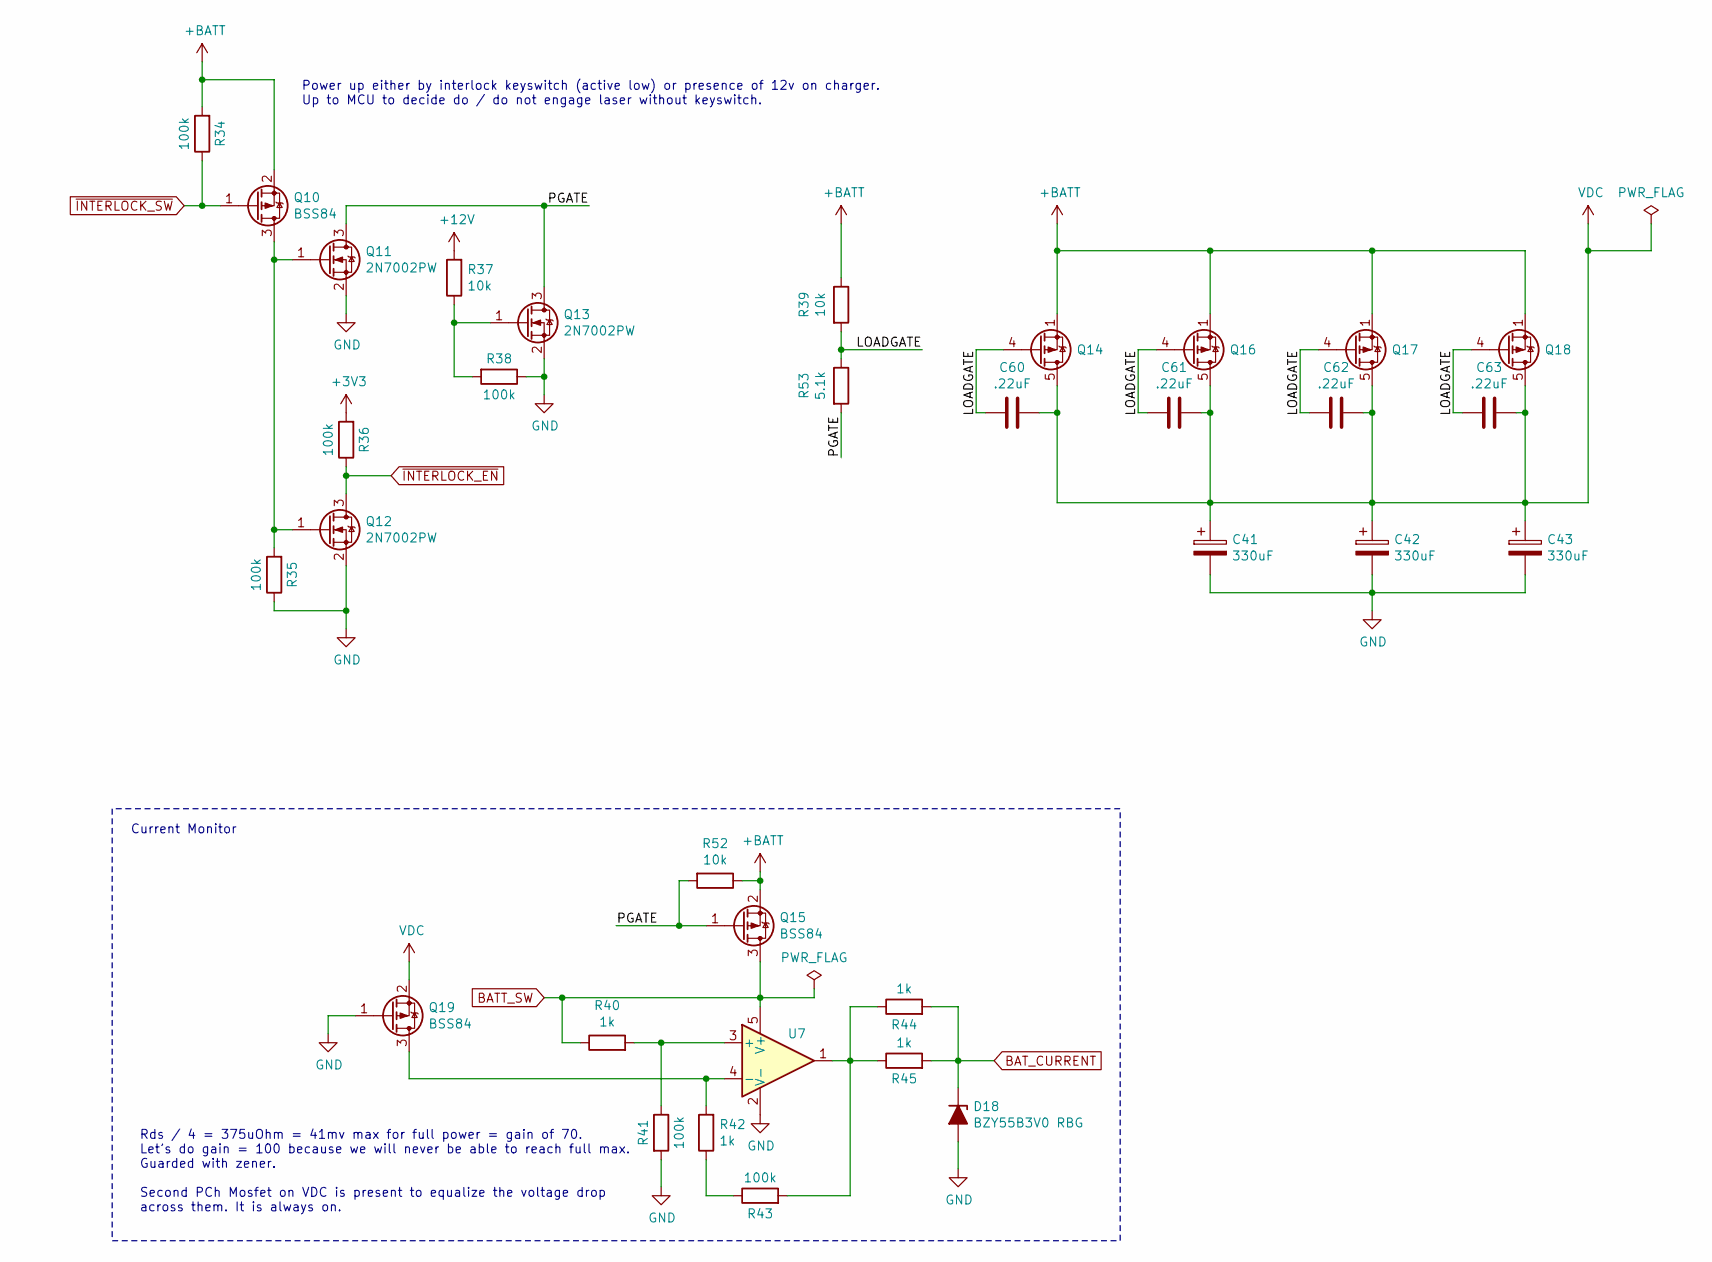
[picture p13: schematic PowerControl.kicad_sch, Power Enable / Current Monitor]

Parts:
C41, C42, C43: 330uF; CP_Elec_10x10; PartNo GYC1E331MCQ1GS
C60, C61, C62, C63: .22uF; C_0603_1608Metric
D18: BZY55B3V0 RBG; D_0805_2012Metric; PartNo BZY55B3V0 RBG
Q10, Q15, Q19: BSS84; SOT-323_SC-70; PartNo BSS84PWH6327XT
Q11, Q12, Q13: 2N7002PW; SOT-323_SC-70; PartNo 2N7002PW,115
Q14, Q16, Q17, Q18: Si7141DP; PowerPAK_SO-8_Single; PartNo SI7141DP-T1-GE3
R34, R35, R36, R38, R41, R43: 100k; R_0805_2012Metric; PartNo SFR10EZPJ104
R37, R39, R52: 10k; R_0805_2012Metric; PartNo ERJ-6ENF1002V
R40, R42, R44, R45: 1k; R_0805_2012Metric; PartNo ERJ-P06J102V
R53: 5.1k; R_0805_2012Metric
U7: LTC2066IS5#TRPBF; SOT-23-5; PartNo LTC2066IS5#TRPBF

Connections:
+3V3: R36.2; also elsewhere on the board
+12V: R37.2; also elsewhere on the board
+BATT: Q10.2 (S), Q14.1 (S), Q14.2 (S), Q14.3 (S), Q15.2 (S), Q16.1 (S), Q16.2 (S), Q16.3 (S), Q17.1 (S), Q17.2 (S), Q17.3 (S), Q18.1 (S), Q18.2 (S), Q18.3 (S), R34.2, R39.1, R52.1; also elsewhere on the board
/PowerControl/LOADGATE: C60.2, C61.2, C62.2, C63.2, Q14.4 (G), Q16.4 (G), Q17.4 (G), Q18.4 (G), R39.2, R53.1
/PowerControl/PGATE: Q11.3 (D), Q13.3 (D), Q15.1 (G), R52.2, R53.2
BATT_SW: Q15.3 (D), R40.1, U7.5 (V+); also elsewhere on the board
BAT_CURRENT: D18.1 (K), R44.2, R45.2; also elsewhere on the board
GND: C41.2, C42.2, C43.2, D18.2 (A), Q11.2 (S), Q12.2 (S), Q13.2 (S), Q19.1 (G), R35.1, R38.1, R41.2, U7.2 (V-); also elsewhere on the board
unnamed: Q10.3 (D), Q11.1 (G), Q12.1 (G), R35.2
unnamed: Q13.1 (G), R37.1, R38.2
unnamed: Q19.3 (D), R42.2, U7.4 (-)
unnamed: R42.1, R43.1
unnamed: R43.2, R44.1, R45.1, U7.1
unnamed: R40.2, R41.1, U7.3 (+)
VDC: C41.1, C42.1, C43.1, C60.1, C61.1, C62.1, C63.1, Q14.5 (D), Q16.5 (D), Q17.5 (D), Q18.5 (D), Q19.2 (S); also elsewhere on the board
~INTERLOCK_EN: Q12.3 (D), R36.1; also elsewhere on the board
~INTERLOCK_SW: Q10.1 (G), R34.1; also elsewhere on the board

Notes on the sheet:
Power up either by interlock keyswitch (active low) or presence of 12v on charger. Up to MCU to decide do / do not engage laser without keyswitch.
Current Monitor
Rds / 4 = 375uOhm = 41mv max for full power = gain of 70. Let’s do gain = 100 because we will never be able to reach full max. Guarded with zener. Second PCh Mosfet on VDC is present to equalize the voltage drop across them. It is always on.

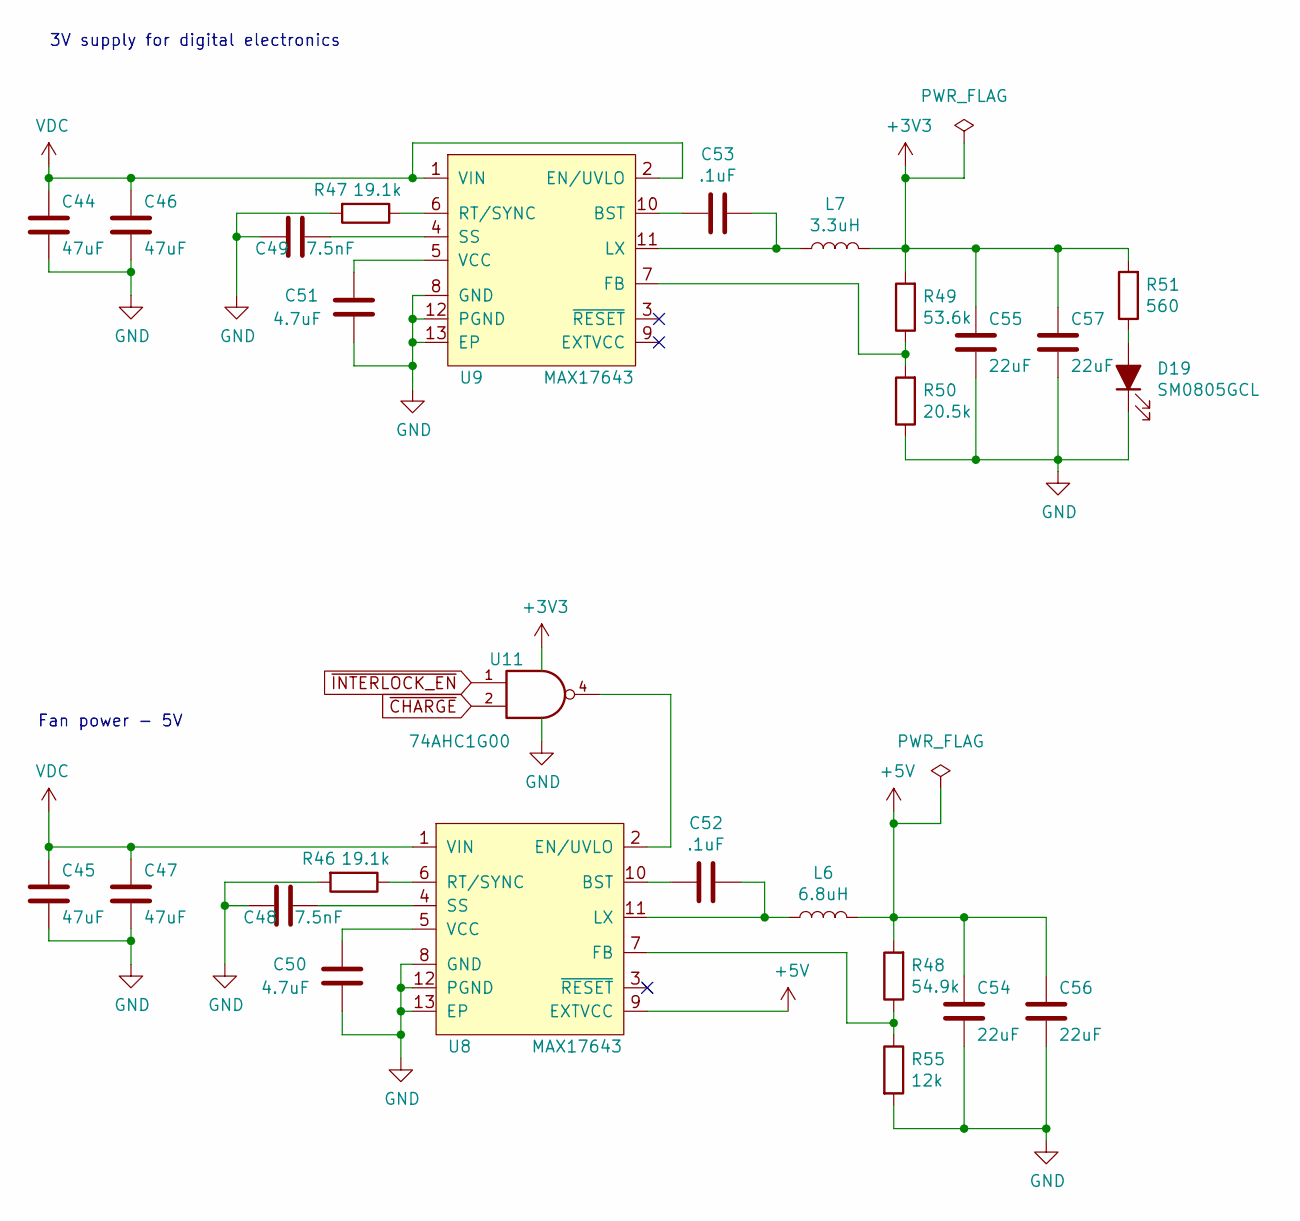
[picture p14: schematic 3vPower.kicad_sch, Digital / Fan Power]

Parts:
C44, C45, C46, C47: 47uF; C_1206_3216Metric; PartNo C3216JB1E476M160AC
C48, C49: 7.5nF; C_0805_2012Metric; PartNo C0805C752F8HACTU
C50, C51: 4.7uF; C_0805_2012Metric; PartNo JMK212B7475KGHT
C52, C53: .1uF; C_0805_2012Metric; PartNo C0805X104M5RACTU
C54, C55, C56, C57: 22uF; C_1206_3216Metric; PartNo C3216X5R1V226M160AC
D19: SM0805GCL; LED_0805_2012Metric; PartNo SM0805GCL
L6: 6.8uH; Inductor_SRP0412; PartNo SRP0412-6R8K
L7: 3.3uH; Inductor_SRP0412; PartNo SRP0412-3R3K
R46, R47: 19.1k; R_0805_2012Metric; PartNo ERJ-6ENF1912V
R48: 54.9k; R_0805_2012Metric; PartNo ERJ-6ENF5492V
R49: 53.6k; R_0805_2012Metric; PartNo ERJ-6ENF5362V
R50: 20.5k; R_0805_2012Metric; PartNo ERJ-6ENF2052V
R51: 560; R_0805_2012Metric; PartNo ERJ-6ENF5600V
R55: 12k; R_0805_2012Metric; PartNo ERJ-P06F1202V
U8, U9: MAX17643; DFN-12-1EP_3x3mm_P0.5mm_EP2.05x2.5mm; PartNo MAX17643ATC+
U11: 74AHC1G00; SOT-23-5; PartNo SN74AHC1G00DBVR

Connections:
+3V3: C55.2, C57.2, L7.2, R49.2, R51.2, U11.5 (VCC); also elsewhere on the board
+5V: C54.2, C56.2, L6.2, R48.2, U8.9 (EXTVCC); also elsewhere on the board
GND: C44.1, C45.1, C46.1, C47.1, C48.2, C49.2, C50.1, C51.1, C54.1, C55.1, C56.1, C57.1, D19.1 (K), R46.2, R47.2, R50.1, R55.2, U8.8 (GND), U8.12 (PGND), U8.13 (EP), U9.8 (GND), U9.12 (PGND), U9.13 (EP), U11.3 (GND); also elsewhere on the board
unnamed: D19.2 (A), R51.1
unnamed: C52.2, U8.10 (BST)
unnamed: U8.2 (EN/UVLO), U11.4
unnamed: R48.1, R55.1, U8.7 (FB)
unnamed: C52.1, L6.1, U8.11 (LX)
unnamed: R46.1, U8.6 (RT/SYNC)
unnamed: C48.1, U8.4 (SS)
unnamed: C50.2, U8.5 (VCC)
unnamed: C53.2, U9.10 (BST)
unnamed: R49.1, R50.2, U9.7 (FB)
unnamed: C53.1, L7.1, U9.11 (LX)
unnamed: R47.1, U9.6 (RT/SYNC)
unnamed: C49.1, U9.4 (SS)
unnamed: C51.2, U9.5 (VCC)
VDC: C44.2, C45.2, C46.2, C47.2, U8.1 (VIN), U9.1 (VIN), U9.2 (EN/UVLO); also elsewhere on the board
~CHARGE: U11.2; also elsewhere on the board
~INTERLOCK_EN: U11.1; also elsewhere on the board

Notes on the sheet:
Fan power - 5V
3V supply for digital electronics

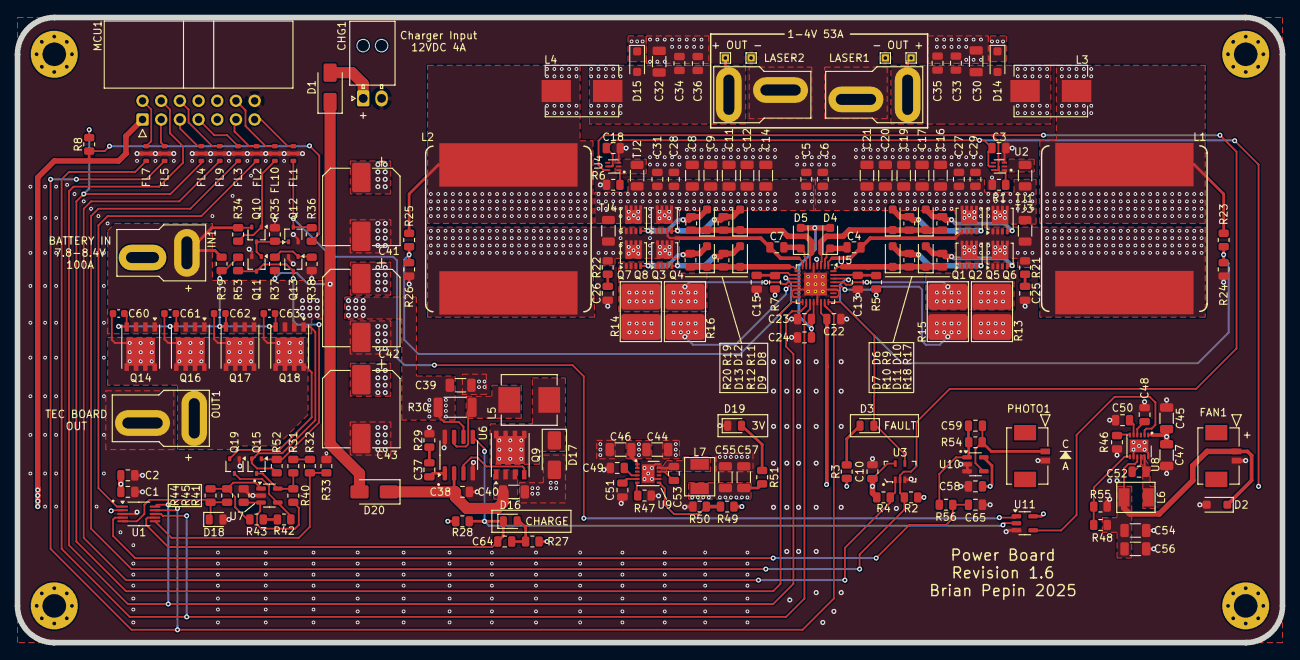
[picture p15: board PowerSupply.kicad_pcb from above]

Board: 4 copper layers, 172.0 x 85.0 mm, 206 parts (0 on the bottom side), 94 nets.

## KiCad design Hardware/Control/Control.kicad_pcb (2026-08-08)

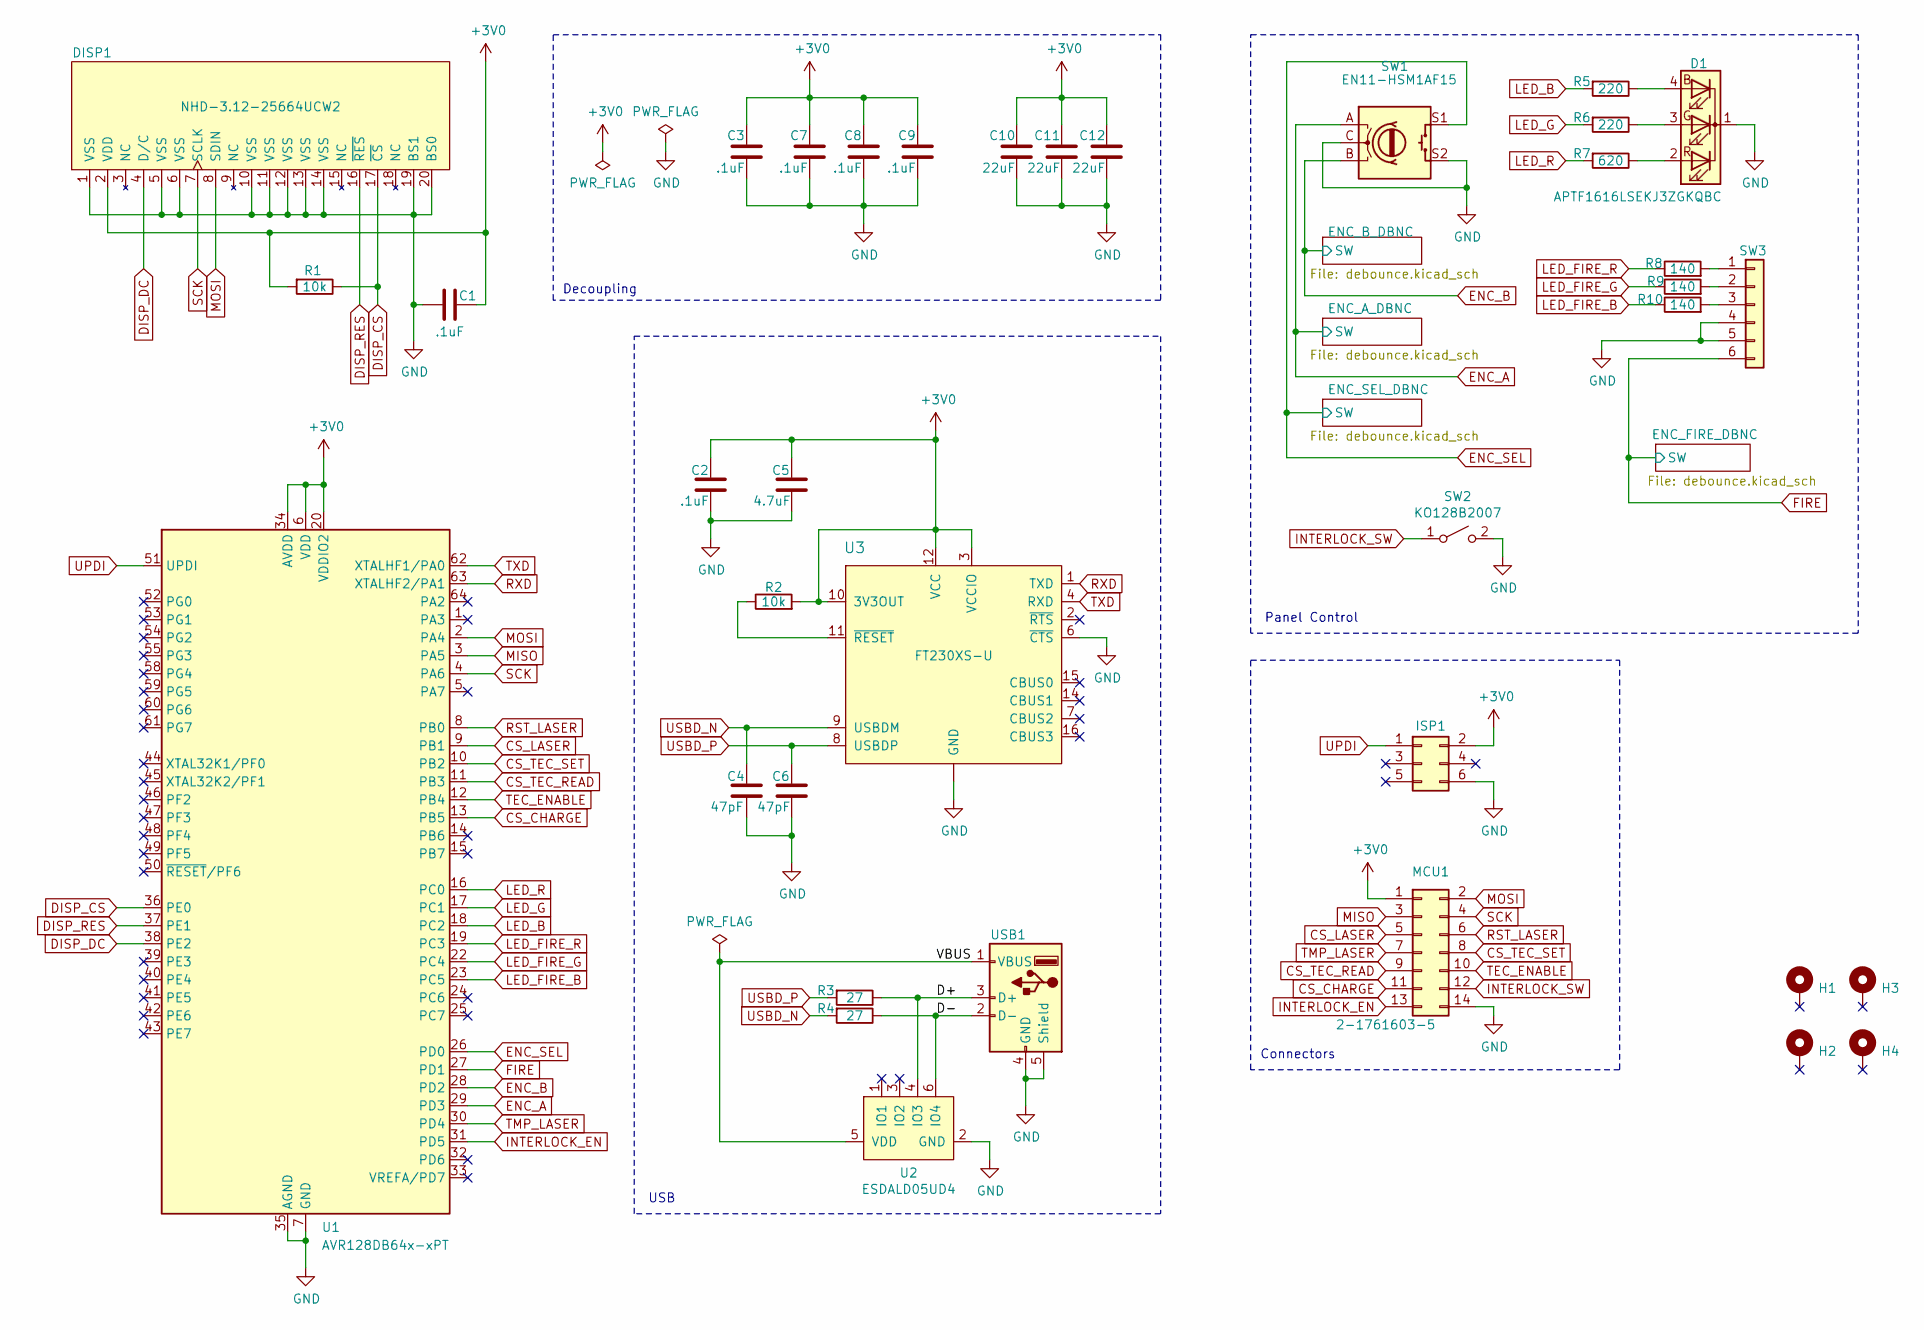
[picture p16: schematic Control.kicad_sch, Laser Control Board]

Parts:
C1, C2, C3, C7, C8, C9: .1uF; C_0805_2012Metric
C4, C6: 47pF; C_0805_2012Metric
C5: 4.7uF; C_0805_2012Metric
C10, C11, C12: 22uF; C_1206_3216Metric
D1: APTF1616LSEKJ3ZGKQBC; LED_Kingbright_KRGB_1.6x1.6mm
DISP1: NHD-3.12-25664UCW2; NHD-3.12-25664UC
H1, H2, H3, H4: MountingHole_Pad; MountingHole_3mm_Pad_Via
ISP1: 61200621621; IDC-Header_2x03_P2.54mm_Vertical
MCU1: 2-1761603-5; IDC-Header_2x07_P2.54mm_Vertical
R1, R2: 10k; R_0805_2012Metric
R3, R4: 27; R_0805_2012Metric
R5, R6: 220; R_0805_2012Metric
R7: 620; R_0805_2012Metric
R8, R9, R10: 140; R_0805_2012Metric
SW1: EN11-HSM1AF15; EN11-HSM
SW2: KO128B2007; PinHeader_1x02_P2.54mm_Vertical
SW3: Conn_01x06; PinHeader_1x06_P2.54mm_Vertical
U1: AVR128DB64x-xPT; TQFP-64_10x10mm_P0.5mm
U2: ESDALD05UD4; SOT-23-6
U3: FT230XS-U; SSOP-16_3.9x4.9mm_P0.635mm
USB1: UJ2-A-HR-G-TH; USB-A1HSW6

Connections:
+3V0: C1.2, C2.1, C3.2, C5.1, C7.2, C8.2, C9.2, C10.1, C11.1, C12.1, DISP1.2 (VDD), ISP1.2, MCU1.1, R1.2, R2.2, U1.6 (VDD), U1.20 (VDDIO2), U1.34 (AVDD), U1.56 (VDD), U3.3 (VCCIO), U3.10 (3V3OUT), U3.12 (VCC); also elsewhere on the board
/D+: R3.1, U2.4 (IO3), USB1.3 (D+)
/D-: R4.1, U2.6 (IO4), USB1.2 (D-)
/VBUS: U2.5 (VDD), USB1.1 (VBUS)
CS_CHARGE: MCU1.11, U1.13 (PB5)
CS_LASER: MCU1.5, U1.9 (PB1)
CS_TEC_READ: MCU1.9, U1.11 (PB3)
CS_TEC_SET: MCU1.8, U1.10 (PB2)
DISP_CS: DISP1.17 (~CS), R1.1, U1.36 (PE0)
DISP_DC: DISP1.4 (D/C), U1.38 (PE2)
DISP_RES: DISP1.16 (~RES), U1.37 (PE1)
ENC_A: SW1.A, U1.29 (PD3); also elsewhere on the board
ENC_B: SW1.B, U1.28 (PD2); also elsewhere on the board
ENC_SEL: SW1.S1, U1.26 (PD0); also elsewhere on the board
FIRE: SW3.6, U1.27 (PD1); also elsewhere on the board
GND: C1.1, C2.2, C3.1, C4.2, C5.2, C6.2, C7.1, C8.1, C9.1, C10.2, C11.2, C12.2, D1.1 (K), DISP1.1 (VSS), DISP1.5 (VSS), DISP1.6 (VSS), DISP1.10 (VSS), DISP1.11 (VSS), DISP1.12 (VSS), DISP1.13 (VSS), DISP1.14 (VSS), DISP1.19 (BS1), DISP1.20 (BS0), ISP1.6, MCU1.14, SW1.C, SW1.S2, SW2.2 (B), SW3.4, SW3.5, U1.7 (GND), U1.21 (GND), U1.35 (AGND), U1.57 (GND), U2.2 (GND), U3.5 (GND), U3.6 (~CTS), U3.13 (GND), USB1.4 (GND), USB1.5 (Shield); also elsewhere on the board
INTERLOCK_EN: MCU1.13, U1.31 (PD5)
INTERLOCK_SW: MCU1.12, SW2.1 (A)
LED_B: R5.2, U1.18 (PC2)
LED_FIRE_B: R10.1, U1.23 (PC5)
LED_FIRE_G: R9.1, U1.22 (PC4)
LED_FIRE_R: R8.1, U1.19 (PC3)
LED_G: R6.2, U1.17 (PC1)
LED_R: R7.2, U1.16 (PC0)
MISO: MCU1.3, U1.3 (PA5)
MOSI: DISP1.8 (SDIN), MCU1.2, U1.2 (PA4)
unnamed: D1.4 (BA), R5.1
unnamed: D1.3 (GA), R6.1
unnamed: D1.2 (RA), R7.1
unnamed: R8.2, SW3.1
unnamed: R9.2, SW3.2
unnamed: R10.2, SW3.3
unnamed: R2.1, U3.11 (~RESET)
RST_LASER: MCU1.6, U1.8 (PB0)
RXD: U1.63 (XTALHF2/PA1), U3.1 (TXD)
SCK: DISP1.7 (SCLK), MCU1.4, U1.4 (PA6)
TEC_ENABLE: MCU1.10, U1.12 (PB4)
TMP_LASER: MCU1.7, U1.30 (PD4)
TXD: U1.62 (XTALHF1/PA0), U3.4 (RXD)
UPDI: ISP1.1, U1.51 (UPDI)
USBD_N: C4.1, R4.2, U3.9 (USBDM)
USBD_P: C6.1, R3.2, U3.8 (USBDP)

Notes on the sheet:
USB
Connectors
Panel Control
Decoupling

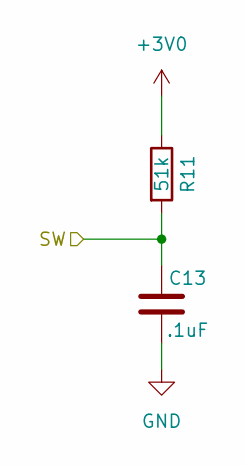
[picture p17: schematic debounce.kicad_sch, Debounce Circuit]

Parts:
C13: .1uF; C_0805_2012Metric
R11: 51k; R_0805_2012Metric

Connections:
+3V0: R11.1; also elsewhere on the board
ENC_B: C13.1, R11.2; also elsewhere on the board
GND: C13.2; also elsewhere on the board

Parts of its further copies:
C14, C15, C16: .1uF; C_0805_2012Metric
R12, R13, R14: 51k; R_0805_2012Metric

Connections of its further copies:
+3V0: R12.1, R13.1, R14.1; also elsewhere on the board
ENC_A: C14.1, R12.2; also elsewhere on the board
ENC_SEL: C15.1, R13.2; also elsewhere on the board
FIRE: C16.1, R14.2; also elsewhere on the board
GND: C14.2, C15.2, C16.2; also elsewhere on the board

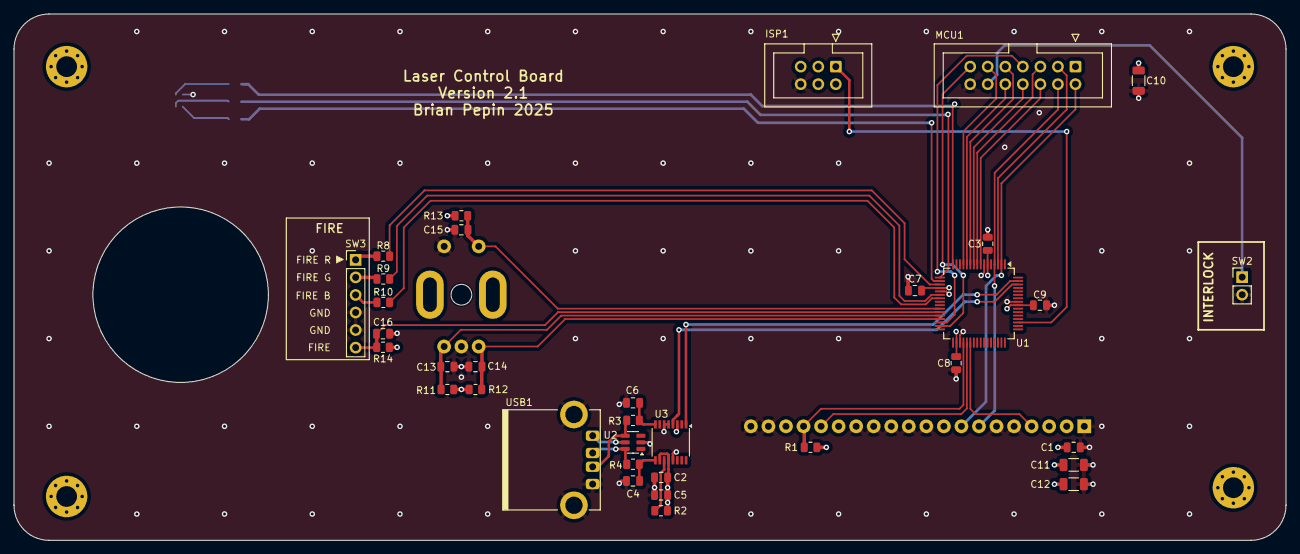
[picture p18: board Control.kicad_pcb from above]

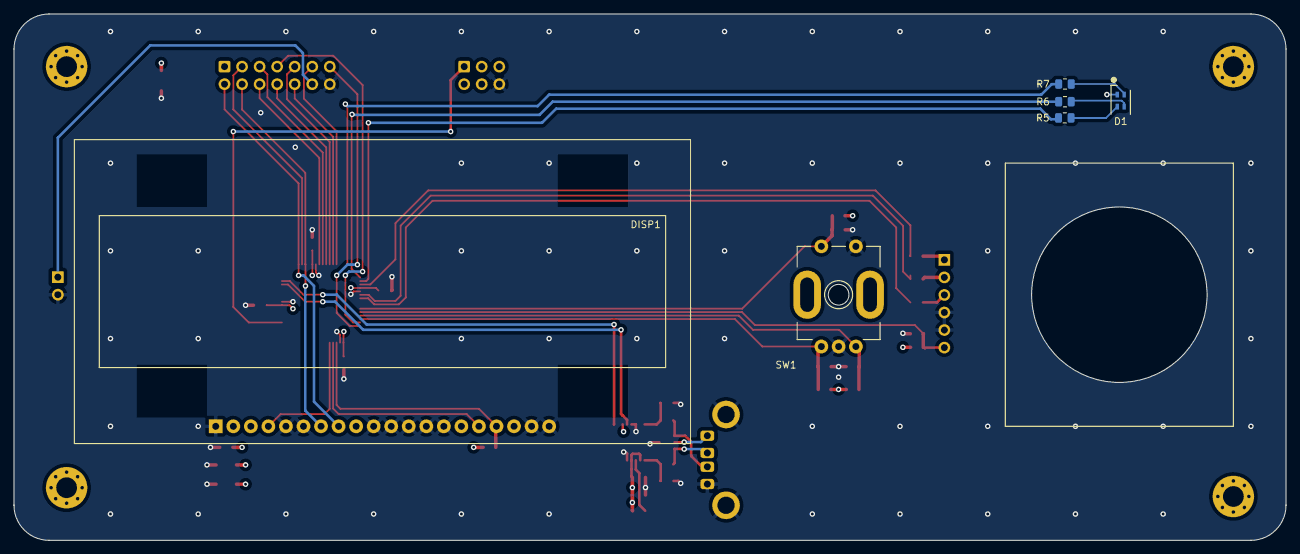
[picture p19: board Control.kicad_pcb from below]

Board: 4 copper layers, 184.2 x 76.2 mm, 45 parts (6 on the bottom side), 42 nets.

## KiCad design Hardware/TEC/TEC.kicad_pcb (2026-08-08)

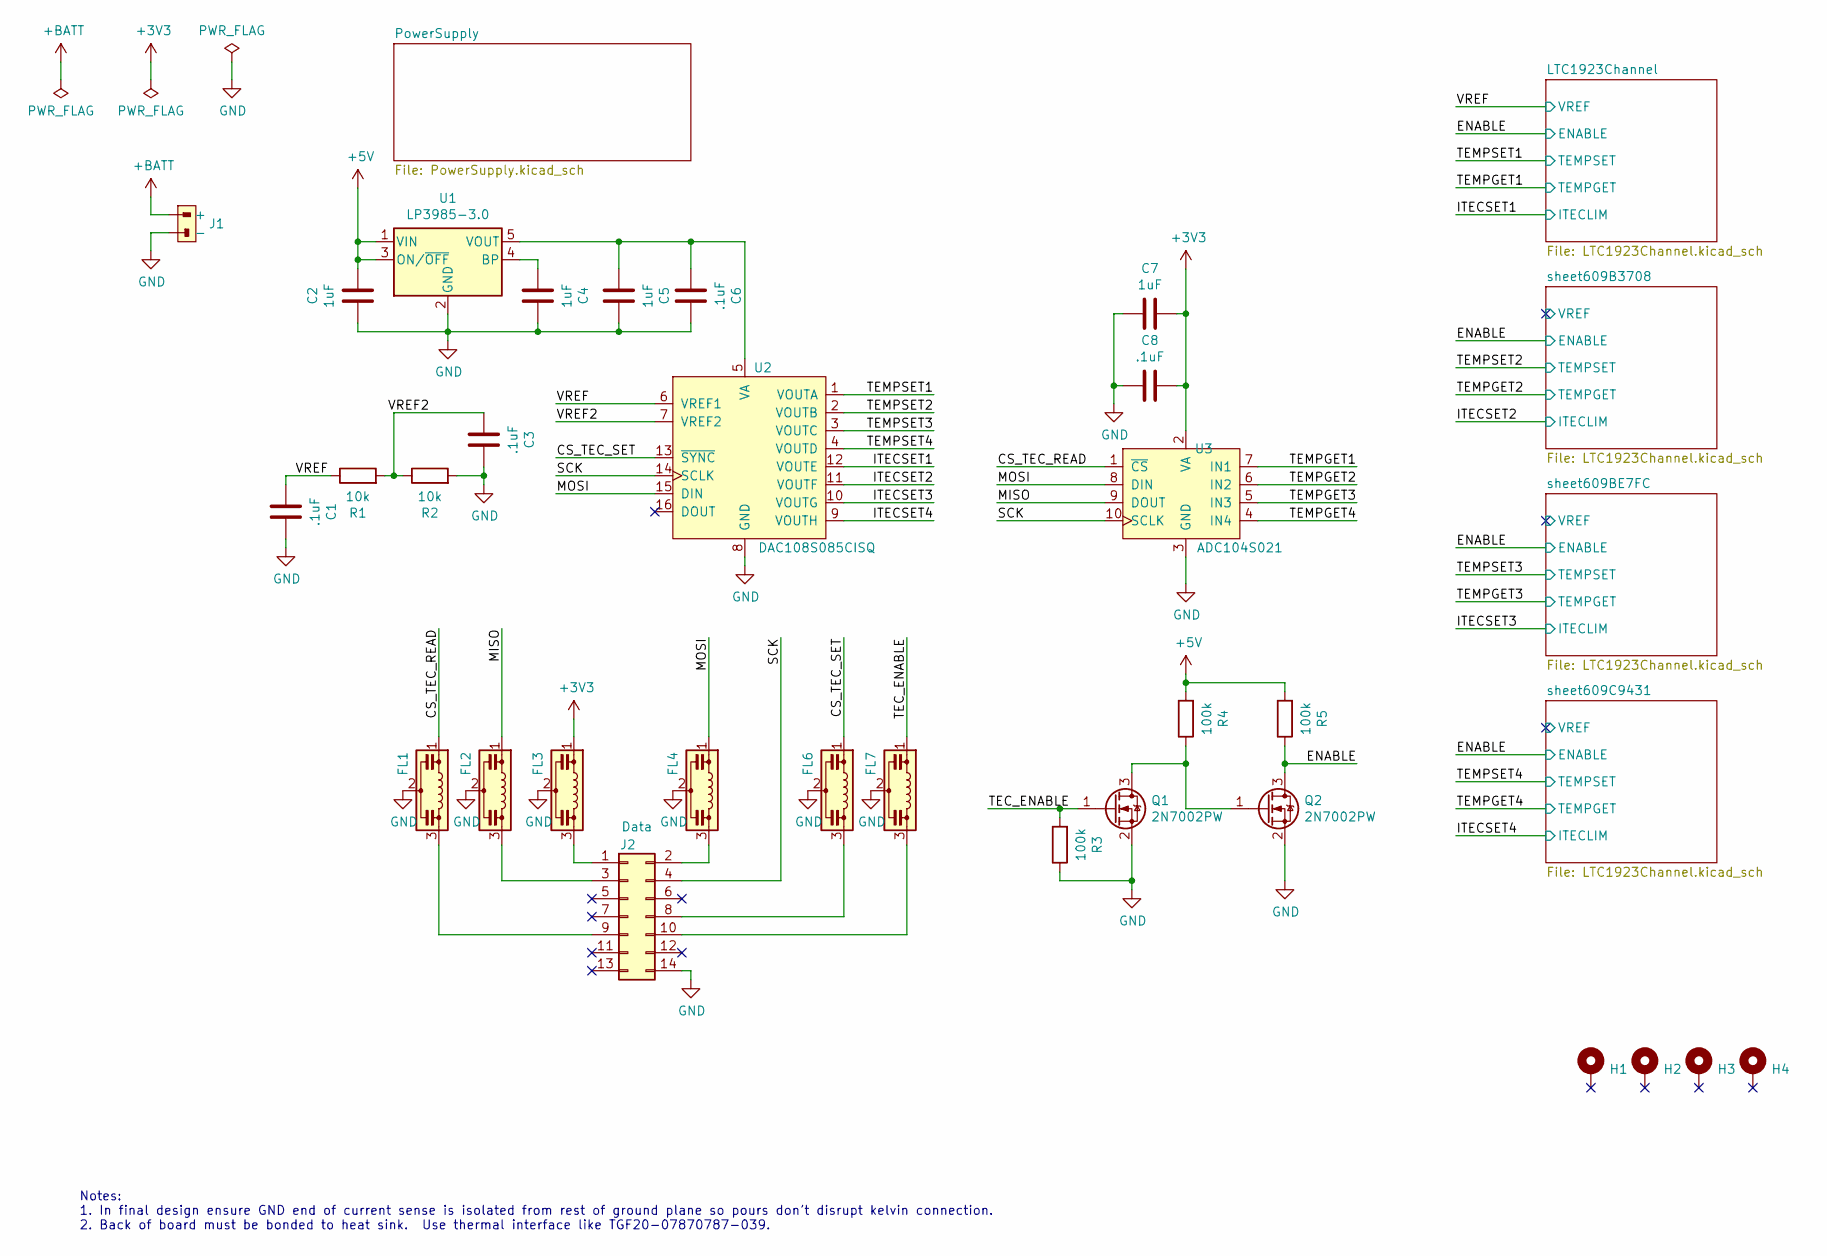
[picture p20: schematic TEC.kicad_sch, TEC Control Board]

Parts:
C1, C3, C6, C8: .1uF; C_0805_2012Metric; PartNo VJ0805Y104KXXAT
C2, C4, C5, C7: 1uF; C_0805_2012Metric; PartNo UMF212B7105KGHT
FL1, FL2, FL3, FL4, FL6, FL7: NFL21SP206X1C7D; EMI_805; PartNo NFL21SP206X1C7D
H1, H2, H3, H4: MountingHole_Pad; MountingHole_3mm_Pad_Via
J1: DEANS; Connector_Deans_Male
J2: Data; IDC-Header_2x07_P2.54mm_Horizontal; PartNo 2-1761605-5
Q1, Q2: 2N7002PW; SOT-23; PartNo 2N7002PW,115
R1, R2: 10k; R_0805_2012Metric; PartNo AC0805FR-0710KL
R3, R4, R5: 100k; R_0805_2012Metric; PartNo RC0805FR-07100KL
U1: LP3985-3.0; SOT-23-5; PartNo LP3985IM5X-3.0/NOPB
U2: DAC108S085CISQ; WQFN-16-1EP_4x4mm_P0.5mm_EP2.6x2.6mm_ThermalVias; PartNo DAC108S085CISQ/NOPB
U3: ADC104S021; VSSOP-10_3x3mm_P0.5mm; PartNo ADC104S021CIMMX/NOPB

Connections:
+3V3: C7.1, C8.1, FL3.1, U3.2 (VA)
+5V: C2.1, R4.2, R5.2, U1.1 (VIN), U1.3 (ON/~OFF); also elsewhere on the board
+BATT: J1.+; also elsewhere on the board
/CS_TEC_READ: FL1.1, U3.1 (~CS)
/CS_TEC_SET: FL6.1, U2.13 (~SYNC)
/ENABLE: Q2.3 (D), R5.1; also elsewhere on the board
/ITECSET1: U2.12 (VOUTE); also elsewhere on the board
/ITECSET2: U2.11 (VOUTF); also elsewhere on the board
/ITECSET3: U2.10 (VOUTG); also elsewhere on the board
/ITECSET4: U2.9 (VOUTH); also elsewhere on the board
/MISO: FL2.1, U3.9 (DOUT)
/MOSI: FL4.1, U2.15 (DIN), U3.8 (DIN)
/SCK: J2.4, U2.14 (SCLK), U3.10 (SCLK)
/TEC_ENABLE: FL7.1, Q1.1 (G), R3.2
/TEMPGET1: U3.7 (IN1); also elsewhere on the board
/TEMPGET2: U3.6 (IN2); also elsewhere on the board
/TEMPGET3: U3.5 (IN3); also elsewhere on the board
/TEMPGET4: U3.4 (IN4); also elsewhere on the board
/TEMPSET1: U2.1 (VOUTA); also elsewhere on the board
/TEMPSET2: U2.2 (VOUTB); also elsewhere on the board
/TEMPSET3: U2.3 (VOUTC); also elsewhere on the board
/TEMPSET4: U2.4 (VOUTD); also elsewhere on the board
/VREF: C1.2, R1.1, U2.6 (VREF1); also elsewhere on the board
/VREF2: C3.2, R1.2, R2.1, U2.7 (VREF2)
GND: C1.1, C2.2, C3.1, C4.1, C5.1, C6.1, C7.2, C8.2, FL1.2, FL2.2, FL3.2, FL4.2, FL6.2, FL7.2, J1.-, J2.14, Q1.2 (S), Q2.2 (S), R2.2, R3.1, U1.2 (GND), U2.8 (GND), U2.17 (GND), U3.3 (GND); also elsewhere on the board
unnamed: FL3.3, J2.1
unnamed: FL4.3, J2.2
unnamed: FL2.3, J2.3
unnamed: FL6.3, J2.8
unnamed: FL1.3, J2.9
unnamed: FL7.3, J2.10
unnamed: Q1.3 (D), Q2.1 (G), R4.1
unnamed: C4.2, U1.4 (BP)
unnamed: C5.2, C6.2, U1.5 (VOUT), U2.5 (VA)

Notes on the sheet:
Notes: 1. In final design ensure GND end of current sense is isolated from rest of ground plane so pours don’t disrupt kelvin connection. 2. Back of board must be bonded to heat sink. Use thermal interface like TGF20-07870787-039.


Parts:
C9, C11: .1uF film; C_0805_2012Metric; PartNo FCA0805C104M-J2
C10, C14, C16, C17, C20, C24, C26, C28: .1uF; C_0805_2012Metric; PartNo VJ0805Y104KXXAT
C12, C15, C23: 1uF; C_0805_2012Metric; PartNo UMF212B7105KGHT
C13: 4.7uF tant; C_0805_2012Metric; PartNo T529P475M025AAE300
C18, C19, C29: 10uF; C_0805_2012Metric; PartNo C2012X7S1E106K125AE
C21, C25, C27, C30: 4.7uF; C_0805_2012Metric; PartNo C0805C475K3RACTU
C22: 150pF; C_0805_2012Metric; PartNo C0805C151J5GACTU
C31, C33: 22uF; C_1206_3216Metric; PartNo 12063D226MAT2A
C32: 47uF; C_1206_3216Metric; PartNo C3216X5R1E476M160AC
D1: RED; LED_0805_2012Metric; PartNo APT2012LSECK/J3-PRV
D2: BLU; LED_0805_2012Metric; PartNo 5973605607F
D3: YEL; LED_0805_2012Metric; PartNo SM0805YCL
J3: Conn_01x04; Molex_Nano-Fit_105313-xx04_1x04_P2.50mm_Horizontal; PartNo 105313-1304
L1, L2: 10uH; L_Pulse_PA4343_2; PartNo PA4343.103ANLT
NT1: Net-Tie_2; NetTie-2_SMD_Pad0.5mm
Q3, Q4, Q5, Q6: 2N7002PW; SOT-23; PartNo 2N7002PW,115
Q7, Q8: SQJ504EP; PowerPAK_SO-8_Dual; PartNo SQJ504EP-T1_GE3
R6: 15.4k 1%; R_0805_2012Metric; PartNo ERJ-6ENF1542V
R7: 6.65k 1%; R_0805_2012Metric; PartNo ERJ-6ENF6651V
R8: 13.3k 1%; R_0805_2012Metric; PartNo CRCW080513K3FKEA
R9: 10k 1%; R_0805_2012Metric; PartNo AC0805FR-0710KL
R10, R14, R16: 1.5k; R_0805_2012Metric; PartNo CR0805-FX-1501ELF
R11, R12, R18, R20: 100k; R_0805_2012Metric; PartNo RC0805FR-07100KL
R13: 9.09k 1%; R_0805_2012Metric; PartNo ERJ-6ENF9091V
R15: 1k 1%; R_0805_2012Metric; PartNo RC0805FR-071KL
R17: 1M 1%; R_0805_2012Metric; PartNo RK73H2ARTTD1004F
R19: 10M 1%; R_0805_2012Metric; PartNo CRCW080510M0FKEAC
R21, R23: 10k; R_0805_2012Metric; PartNo AC0805FR-0710KL
R22: 82k; R_0805_2012Metric; PartNo ERJ-6ENF8202V
R24, R26: 8060; R_0805_2012Metric; PartNo CR0805-FX-8061ELF
R25, R27: 2050; R_0805_2012Metric; PartNo CR0805-FX-2051ELF
R28: .010; R_2010_5025Metric; PartNo TLR2HWDTE10L0F75
U4: LTC2053; MSOP-8_3x3mm_P0.65mm; PartNo LTC2053IMS8#PBF
U5: LTC1923EUH; QFN-32-1EP_5x5mm_P0.5mm_EP3.45x3.45mm_ThermalVias; PartNo LTC1923EUH#PBF
U6, U7: LTC1693-1; SO-8_3.9x4.9mm_P1.27mm; PartNo LTC1693-1IS8#PBF

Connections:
+5V: C10.2, C16.2, C17.2, C18.2, C19.2, R10.2, R11.2, R12.2, R14.2, R16.2, R18.2, R20.2, U4.8 (V+), U5.21 (VDD), U5.22 (VDD); also elsewhere on the board
+VDC: C20.2, C21.2, C24.2, C25.2, C26.2, C27.2, C28.2, C29.1, C30.2, C32.1, Q7.3 (S2), Q8.3 (S2), U6.6 (VCC2), U6.8 (VCC1), U7.6 (VCC2), U7.8 (VCC1); also elsewhere on the board
/ENABLE: U5.32 (~SDSYNC); also elsewhere on the board
/ITECSET1: U5.7 (ILIM); also elsewhere on the board
/LTC1923Channel/HC: Q6.1 (G), R20.1, U5.11 (H/C)
/LTC1923Channel/TECN: C33.2, J3.2, L2.1, R26.2
/LTC1923Channel/TECP: C31.2, J3.1, L1.2, R24.2
/LTC1923Channel/~FAULT: Q4.1 (G), R12.1, U5.9 (~FAULT)
/TEMPGET1: J3.3, R6.2, R9.2; also elsewhere on the board
/TEMPSET1: R7.2; also elsewhere on the board
/VREF: C12.1, C23.1, R6.1, R15.1, R17.2, U4.5 (REF), U5.8 (VSET), U5.27 (VREF); also elsewhere on the board
GND: C9.2, C10.1, C12.2, C14.2, C15.1, C16.1, C17.1, C18.1, C19.1, C20.1, C21.1, C22.2, C23.2, C24.1, C25.1, C26.1, C27.1, C28.1, C29.2, C30.1, C31.1, C32.2, C33.1, J3.4, NT1.2, Q3.2 (S), Q4.2 (S), Q5.2 (S), Q6.2 (S), R8.1, R22.2, R23.1, R25.1, R27.1, R28.1, U4.1 (~EN), U4.4 (V-), U5.4 (AGND), U5.20 (PGND), U5.33 (PGND), U6.2 (GND1), U6.4 (GND2), U7.2 (GND1), U7.4 (GND2); also elsewhere on the board
unnamed: C14.1, R21.2
unnamed: D1.2 (A), R10.1
unnamed: D1.1 (K), Q3.3 (D)
unnamed: D2.2 (A), R14.1
unnamed: D2.1 (K), Q5.3 (D)
unnamed: D3.2 (A), R16.1
unnamed: D3.1 (K), Q5.1 (G), Q6.3 (D), R18.1
unnamed: Q3.1 (G), Q4.3 (D), R11.1
unnamed: L1.1, Q7.5 (D1), Q7.6 (D2)
unnamed: Q7.2 (G1), U6.7 (OUT1)
unnamed: Q7.4 (G2), U6.5 (OUT2)
unnamed: Q7.1 (S1), Q8.1 (S1), R28.2, U5.17 (CS+)
unnamed: L2.2, Q8.5 (D1), Q8.6 (D2)
unnamed: Q8.2 (G1), U7.7 (OUT1)
unnamed: Q8.4 (G2), U7.5 (OUT2)
unnamed: C9.1, R9.1, U4.3 (+IN), U5.10 (VTHRM)
unnamed: R7.1, R8.2, U4.2 (-IN)
unnamed: C11.1, R13.1, U4.7 (OUT), U5.1 (CNTRL)
unnamed: C11.2, R13.2, R15.2, U4.6 (RG)
unnamed: NT1.1, U5.16 (CS-)
unnamed: C22.1, U5.28 (CT)
unnamed: C13.2, R19.1, U5.2 (EAOUT)
unnamed: C13.1, R17.1, R19.2, U5.3 (FB)
unnamed: U5.19 (NDRVA), U7.1 (IN1)
unnamed: U5.23 (NDRVB), U6.1 (IN1)
unnamed: U5.18 (PDRVA), U6.3 (IN2)
unnamed: U5.24 (PDRVB), U7.3 (IN2)
unnamed: R21.1, U5.30 (PLLLPF)
unnamed: R22.1, U5.31 (RSLEW)
unnamed: R23.2, U5.29 (RT)
unnamed: C15.2, U5.6 (SS)
unnamed: R24.1, R25.2, U5.14 (TEC+)
unnamed: R26.1, R27.2, U5.13 (TEC-)

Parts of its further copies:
C36, C38, C61, C63, C86, C88: .1uF film; C_0805_2012Metric; PartNo FCA0805C104M-J2
C37, C41, C43, C44, C47, C51, C53, C55, C62, C66, C68, C69, C72, C76, C78, C80, C87, C91, C93, C94, C97, C101, C103, C105: .1uF; C_0805_2012Metric; PartNo VJ0805Y104KXXAT
C39, C42, C50, C64, C67, C75, C89, C92, C100: 1uF; C_0805_2012Metric; PartNo UMF212B7105KGHT
C40, C65, C90: 4.7uF tant; C_0805_2012Metric; PartNo T529P475M025AAE300
C45, C46, C56, C70, C71, C81, C95, C96, C106: 10uF; C_0805_2012Metric; PartNo C2012X7S1E106K125AE
C48, C52, C54, C57, C73, C77, C79, C82, C98, C102, C104, C107: 4.7uF; C_0805_2012Metric; PartNo C0805C475K3RACTU
C49, C74, C99: 150pF; C_0805_2012Metric; PartNo C0805C151J5GACTU
C58, C60, C83, C85, C108, C110: 22uF; C_1206_3216Metric; PartNo 12063D226MAT2A
C59, C84, C109: 47uF; C_1206_3216Metric; PartNo C3216X5R1E476M160AC
D4, D7, D10: RED; LED_0805_2012Metric; PartNo APT2012LSECK/J3-PRV
D5, D8, D11: BLU; LED_0805_2012Metric; PartNo 5973605607F
D6, D9, D12: YEL; LED_0805_2012Metric; PartNo SM0805YCL
J4, J5, J6: Conn_01x04; Molex_Nano-Fit_105313-xx04_1x04_P2.50mm_Horizontal; PartNo 105313-1304
L3, L4, L5, L6, L7, L8: 10uH; L_Pulse_PA4343_2; PartNo PA4343.103ANLT
NT2, NT3, NT4: Net-Tie_2; NetTie-2_SMD_Pad0.5mm
Q12, Q13, Q14, Q15, Q18, Q19, Q20, Q21, Q24, Q25, Q26, Q27: 2N7002PW; SOT-23; PartNo 2N7002PW,115
Q16, Q17, Q22, Q23, Q28, Q29: SQJ504EP; PowerPAK_SO-8_Dual; PartNo SQJ504EP-T1_GE3
R31, R54, R77: 15.4k 1%; R_0805_2012Metric; PartNo ERJ-6ENF1542V
R32, R55, R78: 6.65k 1%; R_0805_2012Metric; PartNo ERJ-6ENF6651V
R33, R56, R79: 13.3k 1%; R_0805_2012Metric; PartNo CRCW080513K3FKEA
R34, R57, R80: 10k 1%; R_0805_2012Metric; PartNo AC0805FR-0710KL
R35, R39, R41, R58, R62, R64, R81, R85, R87: 1.5k; R_0805_2012Metric; PartNo CR0805-FX-1501ELF
R36, R37, R43, R45, R59, R60, R66, R68, R82, R83, R89, R91: 100k; R_0805_2012Metric; PartNo RC0805FR-07100KL
R38, R61, R84: 9.09k 1%; R_0805_2012Metric; PartNo ERJ-6ENF9091V
R40, R63, R86: 1k 1%; R_0805_2012Metric; PartNo RC0805FR-071KL
R42, R65, R88: 1M 1%; R_0805_2012Metric; PartNo RK73H2ARTTD1004F
R44, R67, R90: 10M 1%; R_0805_2012Metric; PartNo CRCW080510M0FKEAC
R46, R48, R69, R71, R92, R94: 10k; R_0805_2012Metric; PartNo AC0805FR-0710KL
R47, R70, R93: 82k; R_0805_2012Metric; PartNo ERJ-6ENF8202V
R49, R51, R72, R74, R95, R97: 8060; R_0805_2012Metric; PartNo CR0805-FX-8061ELF
R50, R52, R73, R75, R96, R98: 2050; R_0805_2012Metric; PartNo CR0805-FX-2051ELF
R53, R76, R99: .010; R_2010_5025Metric; PartNo TLR2HWDTE10L0F75
U9, U13, U17: LTC2053; MSOP-8_3x3mm_P0.65mm; PartNo LTC2053IMS8#PBF
U10, U14, U18: LTC1923EUH; QFN-32-1EP_5x5mm_P0.5mm_EP3.45x3.45mm_ThermalVias; PartNo LTC1923EUH#PBF
U11, U12, U15, U16, U19, U20: LTC1693-1; SO-8_3.9x4.9mm_P1.27mm; PartNo LTC1693-1IS8#PBF

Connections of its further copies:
+5V: C37.2, C43.2, C44.2, C45.2, C46.2, C62.2, C68.2, C69.2, C70.2, C71.2, C87.2, C93.2, C94.2, C95.2, C96.2, R35.2, R36.2, R37.2, R39.2, R41.2, R43.2, R45.2, R58.2, R59.2, R60.2, R62.2, R64.2, R66.2, R68.2, R81.2, R82.2, R83.2, R85.2, R87.2, R89.2, R91.2, U9.8 (V+), U10.21 (VDD), U10.22 (VDD), U13.8 (V+), U14.21 (VDD), U14.22 (VDD), U17.8 (V+), U18.21 (VDD), U18.22 (VDD); also elsewhere on the board
+VDC: C47.2, C48.2, C51.2, C52.2, C53.2, C54.2, C55.2, C56.1, C57.2, C59.1, C72.2, C73.2, C76.2, C77.2, C78.2, C79.2, C80.2, C81.1, C82.2, C84.1, C97.2, C98.2, C101.2, C102.2, C103.2, C104.2, C105.2, C106.1, C107.2, C109.1, Q16.3 (S2), Q17.3 (S2), Q22.3 (S2), Q23.3 (S2), Q28.3 (S2), Q29.3 (S2), U11.6 (VCC2), U11.8 (VCC1), U12.6 (VCC2), U12.8 (VCC1), U15.6 (VCC2), U15.8 (VCC1), U16.6 (VCC2), U16.8 (VCC1), U19.6 (VCC2), U19.8 (VCC1), U20.6 (VCC2), U20.8 (VCC1); also elsewhere on the board
/ENABLE: U10.32 (~SDSYNC), U14.32 (~SDSYNC), U18.32 (~SDSYNC); also elsewhere on the board
/ITECSET2: U10.7 (ILIM); also elsewhere on the board
/ITECSET3: U14.7 (ILIM); also elsewhere on the board
/ITECSET4: U18.7 (ILIM); also elsewhere on the board
/TEMPGET2: J4.3, R31.2, R34.2; also elsewhere on the board
/TEMPGET3: J5.3, R54.2, R57.2; also elsewhere on the board
/TEMPGET4: J6.3, R77.2, R80.2; also elsewhere on the board
/TEMPSET2: R32.2; also elsewhere on the board
/TEMPSET3: R55.2; also elsewhere on the board
/TEMPSET4: R78.2; also elsewhere on the board
/sheet609B3708/HC: Q15.1 (G), R45.1, U10.11 (H/C)
/sheet609B3708/TECN: C60.2, J4.2, L4.1, R51.2
/sheet609B3708/TECP: C58.2, J4.1, L3.2, R49.2
/sheet609B3708/VREF: C39.1, C50.1, R31.1, R40.1, R42.2, U9.5 (REF), U10.8 (VSET), U10.27 (VREF)
/sheet609B3708/~FAULT: Q13.1 (G), R37.1, U10.9 (~FAULT)
/sheet609BE7FC/HC: Q21.1 (G), R68.1, U14.11 (H/C)
/sheet609BE7FC/TECN: C85.2, J5.2, L6.1, R74.2
/sheet609BE7FC/TECP: C83.2, J5.1, L5.2, R72.2
/sheet609BE7FC/VREF: C64.1, C75.1, R54.1, R63.1, R65.2, U13.5 (REF), U14.8 (VSET), U14.27 (VREF)
/sheet609BE7FC/~FAULT: Q19.1 (G), R60.1, U14.9 (~FAULT)
/sheet609C9431/HC: Q27.1 (G), R91.1, U18.11 (H/C)
/sheet609C9431/TECN: C110.2, J6.2, L8.1, R97.2
/sheet609C9431/TECP: C108.2, J6.1, L7.2, R95.2
/sheet609C9431/VREF: C89.1, C100.1, R77.1, R86.1, R88.2, U17.5 (REF), U18.8 (VSET), U18.27 (VREF)
/sheet609C9431/~FAULT: Q25.1 (G), R83.1, U18.9 (~FAULT)
GND: C36.2, C37.1, C39.2, C41.2, C42.1, C43.1, C44.1, C45.1, C46.1, C47.1, C48.1, C49.2, C50.2, C51.1, C52.1, C53.1, C54.1, C55.1, C56.2, C57.1, C58.1, C59.2, C60.1, C61.2, C62.1, C64.2, C66.2, C67.1, C68.1, C69.1, C70.1, C71.1, C72.1, C73.1, C74.2, C75.2, C76.1, C77.1, C78.1, C79.1, C80.1, C81.2, C82.1, C83.1, C84.2, C85.1, C86.2, C87.1, C89.2, C91.2, C92.1, C93.1, C94.1, C95.1, C96.1, C97.1, C98.1, C99.2, C100.2, C101.1, C102.1, C103.1, C104.1, C105.1, C106.2, C107.1, C108.1, C109.2, C110.1, J4.4, J5.4, J6.4, NT2.2, NT3.2, NT4.2, Q12.2 (S), Q13.2 (S), Q14.2 (S), Q15.2 (S), Q18.2 (S), Q19.2 (S), Q20.2 (S), Q21.2 (S), Q24.2 (S), Q25.2 (S), Q26.2 (S), Q27.2 (S), R33.1, R47.2, R48.1, R50.1, R52.1, R53.1, R56.1, R70.2, R71.1, R73.1, R75.1, R76.1, R79.1, R93.2, R94.1, R96.1, R98.1, R99.1, U9.1 (~EN), U9.4 (V-), U10.4 (AGND), U10.20 (PGND), U10.33 (PGND), U11.2 (GND1), U11.4 (GND2), U12.2 (GND1), U12.4 (GND2), U13.1 (~EN), U13.4 (V-), U14.4 (AGND), U14.20 (PGND), U14.33 (PGND), U15.2 (GND1), U15.4 (GND2), U16.2 (GND1), U16.4 (GND2), U17.1 (~EN), U17.4 (V-), U18.4 (AGND), U18.20 (PGND), U18.33 (PGND), U19.2 (GND1), U19.4 (GND2), U20.2 (GND1), U20.4 (GND2); also elsewhere on the board
unnamed: C41.1, R46.2
unnamed: C66.1, R69.2
unnamed: C91.1, R92.2
unnamed: D4.2 (A), R35.1
unnamed: D4.1 (K), Q12.3 (D)
unnamed: D5.2 (A), R39.1
unnamed: D5.1 (K), Q14.3 (D)
unnamed: D6.2 (A), R41.1
unnamed: D6.1 (K), Q14.1 (G), Q15.3 (D), R43.1
unnamed: D7.2 (A), R58.1
unnamed: D7.1 (K), Q18.3 (D)
unnamed: D8.2 (A), R62.1
unnamed: D8.1 (K), Q20.3 (D)
unnamed: D9.2 (A), R64.1
unnamed: D9.1 (K), Q20.1 (G), Q21.3 (D), R66.1
unnamed: D10.2 (A), R81.1
unnamed: D10.1 (K), Q24.3 (D)
unnamed: D11.2 (A), R85.1
unnamed: D11.1 (K), Q26.3 (D)
unnamed: D12.2 (A), R87.1
unnamed: D12.1 (K), Q26.1 (G), Q27.3 (D), R89.1
unnamed: Q12.1 (G), Q13.3 (D), R36.1
unnamed: L3.1, Q16.5 (D1), Q16.6 (D2)
unnamed: Q16.2 (G1), U11.7 (OUT1)
unnamed: Q16.4 (G2), U11.5 (OUT2)
unnamed: Q16.1 (S1), Q17.1 (S1), R53.2, U10.17 (CS+)
unnamed: L4.2, Q17.5 (D1), Q17.6 (D2)
unnamed: Q17.2 (G1), U12.7 (OUT1)
unnamed: Q17.4 (G2), U12.5 (OUT2)
unnamed: Q18.1 (G), Q19.3 (D), R59.1
unnamed: L5.1, Q22.5 (D1), Q22.6 (D2)
unnamed: Q22.2 (G1), U15.7 (OUT1)
unnamed: Q22.4 (G2), U15.5 (OUT2)
unnamed: Q22.1 (S1), Q23.1 (S1), R76.2, U14.17 (CS+)
unnamed: L6.2, Q23.5 (D1), Q23.6 (D2)
unnamed: Q23.2 (G1), U16.7 (OUT1)
unnamed: Q23.4 (G2), U16.5 (OUT2)
unnamed: Q24.1 (G), Q25.3 (D), R82.1
unnamed: L7.1, Q28.5 (D1), Q28.6 (D2)
unnamed: Q28.2 (G1), U19.7 (OUT1)
unnamed: Q28.4 (G2), U19.5 (OUT2)
unnamed: Q28.1 (S1), Q29.1 (S1), R99.2, U18.17 (CS+)
unnamed: L8.2, Q29.5 (D1), Q29.6 (D2)
unnamed: Q29.2 (G1), U20.7 (OUT1)
unnamed: Q29.4 (G2), U20.5 (OUT2)
unnamed: R32.1, R33.2, U9.2 (-IN)
unnamed: C38.2, R38.2, R40.2, U9.6 (RG)
unnamed: C38.1, R38.1, U9.7 (OUT), U10.1 (CNTRL)
unnamed: NT2.1, U10.16 (CS-)
unnamed: C49.1, U10.28 (CT)
unnamed: C40.2, R44.1, U10.2 (EAOUT)
unnamed: C40.1, R42.1, R44.2, U10.3 (FB)
unnamed: U10.19 (NDRVA), U12.1 (IN1)
unnamed: U10.23 (NDRVB), U11.1 (IN1)
unnamed: U10.18 (PDRVA), U11.3 (IN2)
unnamed: U10.24 (PDRVB), U12.3 (IN2)
unnamed: R46.1, U10.30 (PLLLPF)
unnamed: R47.1, U10.31 (RSLEW)
unnamed: R48.2, U10.29 (RT)
unnamed: C42.2, U10.6 (SS)
unnamed: R49.1, R50.2, U10.14 (TEC+)
unnamed: R51.1, R52.2, U10.13 (TEC-)
unnamed: C36.1, R34.1, U9.3 (+IN), U10.10 (VTHRM)
unnamed: C61.1, R57.1, U13.3 (+IN), U14.10 (VTHRM)
unnamed: R55.1, R56.2, U13.2 (-IN)
unnamed: C63.1, R61.1, U13.7 (OUT), U14.1 (CNTRL)
unnamed: C63.2, R61.2, R63.2, U13.6 (RG)
unnamed: NT3.1, U14.16 (CS-)
unnamed: C74.1, U14.28 (CT)
unnamed: C65.2, R67.1, U14.2 (EAOUT)
unnamed: C65.1, R65.1, R67.2, U14.3 (FB)
unnamed: U14.19 (NDRVA), U16.1 (IN1)
unnamed: U14.23 (NDRVB), U15.1 (IN1)
unnamed: U14.18 (PDRVA), U15.3 (IN2)
unnamed: U14.24 (PDRVB), U16.3 (IN2)
unnamed: R69.1, U14.30 (PLLLPF)
unnamed: R70.1, U14.31 (RSLEW)
unnamed: R71.2, U14.29 (RT)
unnamed: C67.2, U14.6 (SS)
unnamed: R72.1, R73.2, U14.14 (TEC+)
unnamed: R74.1, R75.2, U14.13 (TEC-)
unnamed: C86.1, R80.1, U17.3 (+IN), U18.10 (VTHRM)
unnamed: R78.1, R79.2, U17.2 (-IN)
unnamed: C88.1, R84.1, U17.7 (OUT), U18.1 (CNTRL)
unnamed: C88.2, R84.2, R86.2, U17.6 (RG)
unnamed: NT4.1, U18.16 (CS-)
unnamed: C99.1, U18.28 (CT)
unnamed: C90.2, R90.1, U18.2 (EAOUT)
unnamed: C90.1, R88.1, R90.2, U18.3 (FB)
unnamed: U18.19 (NDRVA), U20.1 (IN1)
unnamed: U18.23 (NDRVB), U19.1 (IN1)
unnamed: U18.18 (PDRVA), U19.3 (IN2)
unnamed: U18.24 (PDRVB), U20.3 (IN2)
unnamed: R92.1, U18.30 (PLLLPF)
unnamed: R93.1, U18.31 (RSLEW)
unnamed: R94.2, U18.29 (RT)
unnamed: C92.2, U18.6 (SS)
unnamed: R95.1, R96.2, U18.14 (TEC+)
unnamed: R97.1, R98.2, U18.13 (TEC-)

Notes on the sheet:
Gate Driver Bypass
COOL
HEAT
Status Indicators
FAULT


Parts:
C34: 10uF; C_0805_2012Metric; PartNo C2012X7S1E106K125AE
C35: 22uF; C_1206_3216Metric; PartNo 12063D226MAT2A
Q9: 2N7002PW; SOT-23; PartNo 2N7002PW,115
Q10, Q11: Si7141DP; PowerPAK_SO-8_Single; PartNo SI7141DP-T1-GE3
R29, R30: 100k; R_0805_2012Metric; PartNo RC0805FR-07100KL
U8: TPS7A26; WSON-6-1EP_2x2mm_P0.65mm_EP1x1.6mm_ThermalVias; PartNo TPS7A2650DRVR

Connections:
+5V: C35.2, U8.1 (OUT); also elsewhere on the board
+BATT: C34.1, Q10.1 (S), Q10.2 (S), Q10.3 (S), Q11.1 (S), Q11.2 (S), Q11.3 (S), R29.2, R30.2, U8.4 (EN), U8.6 (IN); also elsewhere on the board
+VDC: Q10.5 (D), Q11.5 (D); also elsewhere on the board
GND: C34.2, C35.1, Q9.2 (S), U8.2 (NC), U8.5 (GND), U8.7 (GND); also elsewhere on the board
unnamed: Q9.1 (G), R29.1, U8.3 (PG)
unnamed: Q9.3 (D), Q10.4 (G), Q11.4 (G), R30.1


Board: 4 copper layers, 172.0 x 85.0 mm, 298 parts (0 on the bottom side), 188 nets.

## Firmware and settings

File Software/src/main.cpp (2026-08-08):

#include "globals.h"
#include "config.h"
#include "settings.h"
#include "management.h"

#include <SPI.h>

//
// Global State
//

Settings settings;
DISPLAY_TARGET display(U8G2_R0, Pins::Display::Cs, Pins::Display::Dc, Pins::Display::Reset);
Led led;
Input input;
Laser laser;
Tec tec;

//
// Inputs are handled by a pin change interrupt.
//
ISR(PORTD_PORT_vect)
{
  input.processInterrupt();
}

void setup()
{
  Serial.begin(9600);
  while (!Serial);

  Serial.println(F("\nController starting up..."));

  //
  // Configure LEDs. LEDs are currently configured all on port C
  // but PWM off timer A does not route there. Change the routing to
  // enable PWM on port C before starting LEDs.
  //

  PORTMUX_TCAROUTEA = PORTMUX_TCA0_PORTC_gc;
  led.begin();

  //
  // Configure SPI port
  //

  pinMode(Pins::Spi::Ss, OUTPUT);
  pinMode(Pins::Spi::Miso, INPUT_PULLUP);
  pinMode(Pins::Spi::Mosi, OUTPUT);
  pinMode(Pins::Spi::Sck, OUTPUT);
  digitalWrite(Pins::Spi::Ss, HIGH);

  //
  // Configure display
  //

  pinMode(Pins::Display::Cs, OUTPUT);
  pinMode(Pins::Display::Reset, OUTPUT);
  pinMode(Pins::Display::Dc, OUTPUT);
  display.setBusClock(8000000);
  display.begin();
  display.clear();

  //
  // Read settings from EEPROM and configure
  // power and TEC boards.
  //

  settings.load();

  laser.reset();
  input.reset();

  Serial.println(F("Ready."));
}

void loop()
{
  Management::tick();
}

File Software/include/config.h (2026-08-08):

#pragma once

namespace Pins
{
    namespace Spi
    {
        constexpr static uint8_t Mosi   = PIN_SPI_MOSI;
        constexpr static uint8_t Miso   = PIN_SPI_MISO;
        constexpr static uint8_t Sck    = PIN_SPI_SCK;
        constexpr static uint8_t Ss     = PIN_SPI_SS;
    }

    namespace Inputs
    {
        // All inputs are interrupt driven and must be on the
        // same port.
        constexpr static uint8_t EncoderA           = PIN3;
        constexpr static uint8_t EncoderB           = PIN2;
        constexpr static uint8_t EncoderSel         = PIN0;
        constexpr static uint8_t Fire               = PIN1;
        constexpr static uint8_t InterlockEnable    = PIN5;
        constexpr static uint8_t OverTemp           = PIN4;
        static PORT_t&           Port               = PORTD;
    }

    namespace Tec
    {
        constexpr static uint8_t CsRead = PIN_PB3;
        constexpr static uint8_t CsSet  = PIN_PB2;
        constexpr static uint8_t Enable = PIN_PB4;
    }

    namespace Laser
    {
        constexpr static uint8_t Cs     = PIN_PB1;
        constexpr static uint8_t Reset  = PIN_PB0;
    }

    namespace Power
    {
        constexpr static uint8_t Cs     = PIN_PB5;
    }

    namespace Led
    {
        constexpr static uint8_t Red    = PIN_PC0;
        constexpr static uint8_t Green  = PIN_PC1;
        constexpr static uint8_t Blue   = PIN_PC2;

        constexpr static uint8_t Fire   = PIN_PC3;
        constexpr static uint8_t Ready  = PIN_PC4;
    }

    namespace Display
    {
        constexpr static uint8_t Cs     = PIN_PE0;
        constexpr static uint8_t Dc     = PIN_PE2;
        constexpr static uint8_t Reset  = PIN_PE1;
    }
}

namespace Limits
{
    namespace Current
    {
        constexpr static float Pump1 = 25;
        constexpr static float Pump2 = 25;
    }

    namespace Voltage
    {
        constexpr static float HiBat = 8.4;
        constexpr static float LowBat = 7.5;
        constexpr static float CriticalBat = 7.0;
    }

    namespace Temperature
    {
        constexpr static float DisconnectLimit = -30;
    }
}

namespace Tolerances
{
    namespace Temperature
    {
        constexpr static float Pump = 3.0;
        constexpr static float Vanadate = 5.0;
        constexpr static float Ktp = 1.5;
    }
}

namespace Defaults
{
    namespace Temperatures
    {
        constexpr static float Pump1 = 28;
        constexpr static float Pump2 = 25;
        constexpr static float Vanadate = 23;
        constexpr static float Ktp = 36;
    }

    namespace Currents
    {
        namespace Tec
        {
            constexpr static float Pump     = 1.0; // 8.4 amps
            constexpr static float Vanadate = .85; // 6 amps
            constexpr static float Ktp      = .75; // 5.5 amps
        }
    }
}

namespace Calibration
{
    namespace LaserMonitor
    {
        constexpr static float Slope = .00562979359477001;
        constexpr static float Offset = 0;
    }

    namespace Battery
    {
        namespace Voltage
        {
            constexpr static float Slope = 0.008974358974358974358974358974359;
            constexpr static float Offset = 0.44871794871794871794871794871795;
        }

        namespace Current
        {
            constexpr static float Slope = 1;
            constexpr static float Offset = 0;
        }
    }

    // Current slew when ramping up the pump current
    namespace Slew
    {
        constexpr static float Step = .5;
        constexpr static uint8_t Delay = 10;
    }
}

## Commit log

2025-01-18 Actually add V1.1 files
    [Control 2.kicad_pcb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]
2025-07-25 recover v1 of driver board
    [3vPower.kicad_sch, BatteryCharger.kicad_sch, LaserDriver.kicad_sch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]

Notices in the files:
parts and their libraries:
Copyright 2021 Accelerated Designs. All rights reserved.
